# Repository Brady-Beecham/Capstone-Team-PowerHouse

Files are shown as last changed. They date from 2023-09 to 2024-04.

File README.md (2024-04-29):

# Parking Lot Monitoring System: Ground-Based Solution

## Executive Summary

This project is a continuation project from the 2022-23 academic year at Tennessee Technological University to monitor parking lots in a manner that allows students, faculty, staff, and campus visitors to find parking lots with availability in a timely manner. The previous team used cameras to monitor incoming and outgoing traffic in parking lots.  This solution will not work for many of the parking lots that do not have the infrastructure nearby to support cameras.  By using inductive loops to monitor designated entrances/exits of parking lots, more parking lots across campus can be monitored and students, faculty, etc. can find parking availability without having to search an entire parking lot in hopes of finding an open parking spot.

## Capabilities

Though this project is a continuation project, it deviates away from using cameras and instead uses a ground-based solution. 

The project is capable of...

1. Detecting vehicles entering/exiting parking lots that have designated entrances/exits.
2. Detecting vehicles traveling over the loops at 20 miles per hour or less with an accuracy of about 96%.
3. Using LoRaWAN to transmit data from an ESP32 at a designated entrance/exit of a parking lot to the LoRaWAN gateway. The gateway forwards packets to The Things Stack network server. The data is stored in an application on The Things Stack.
4. Utilizing solar power, wall outlet power, and battery power.

## Salient Outcomes

1. This project will continue the work of creating an effective Parking Lot Monitoring System.

   a. As of September 2023, the Parking Lot Monitoring System is in the second year of the overall project.  This team has inherited a previous system that used cameras to complete both static tracking (monitor parked cars) and dynamic tracking (cars entering and exiting lots) to efficiently monitor parking lots.  This method is a very efficient way to monitor parking lots; however, parking lots that are located away from campus buildings or do not have the infrastructure to support camera placement in the lots do not benefit from this method.  By using a ground-based solution to monitor parking lots with designated entrances/exits, more parking lots can be monitored across the campus of Tennessee Tech.

2. This project will implement the use of solar panels to efficiently power the system.

   a. Some parking lots across the campus of Tennessee Tech are not located near campus buildings.  To allow the system to work in these lots, solar panels will be used to power the system at these lots to efficiently monitor these lots so students, faculty, etc. know if there is parking availability at these specific lots.

3. This project will use LoRaWAN to transmit and receive data from the inductive loop sensor.

   a. LoRaWAN has been chosen for its superior range and lower power draw compared to WiFi.

## Project Demonstration & Images

### Project Video
https://www.youtube.com/watch?v=kGD3eaTffT4

### Project Images



*Charge Controller*

Loop Controller

*Loop Controller*



*Power Controller for Solar Power*



*Wall Power Controller*



*ESP32 Microcontroller with RFM95W LoRa Transceiver*



*Raspberry Pi 4-based LoRaWAN Gateway with WM1302 Concentrator*

## About Us

### Team

Abdulrahman Alrudayan is a senior Electrical Engineering major at Tennessee Technological University.  His interests include power systems and digital design.  The main focus for Abdulrahman is designing the main power system that will distribute power to the entire system through the use of buck converters, step-down transformers, etc.

Khalifah Altamimi is a senior Electrical Engineering major at Tennessee Technological University.  His interests include power systems, robotics, and digital design.  The main focus for Khalifah is designing the backup power system that will provide power to allow the system to continue working when a power outage occurs on campus.  When the system is not being used, it will be charging and stay charged until backup power is needed for the system.

Brady Beecham is a senior Computer Engineering major with a minor in Mathematics at Tennessee Technological University.  His interests include embedded system firmware and design. He spent 7 months as an embedded systems software engineering intern at The Coats Company in Lavergne, TN. The main task Brady has is to power the system using solar power and backup batteries. This is going to be designed as an embedded system that will control the charging and discharging status of the batteries.

Kyle Plant is a senior Computer Engineering major with a minor in Computer Science at Tennessee Technological University.  His interests include programming, FPGA, VLSI, networks, embedded systems, artificial intelligence, automation, and more. He has had three internships during his time as an undergraduate. The first two were at Matheson, a producer of industrial, medical, and specialty gasses as well as gas handling equipment. His first internship at Matheson involved making user-friendly GUI dashboards to display graphs of gas purity or mixture ratio data as well as many other small projects. His second internship at Matheson involved performing general site IT duties as well as a few small projects. His third internship was with QMSI or Quality Manufacturing Systems, Inc. QMSI is an automation and systems integration company that specializes in automated pharmacy systems. At QMSI he worked with AutoCAD to make drawings for the conveyor lines and motor panels. The main focus for Kyle is designing a system to collect data from the loop detector, transmit data to a central computer, and store this data in a database within the central computer. This will involve microcontroller programming, wireless networking, and database management.

Michael Sisk is a senior Electrical Engineering major at Tennessee Technological University.  His interests include power systems, robotics, and automation.  He has spent eight months interning at Jack Daniels Distillery in Lynchburg, TN as an engineering maintenance intern.  He is also currently serving as the Engineering Joint Council (EJC) Representative for the student chapter of the Institute of Electrical and Electronics Engineers (IEEE).  The main focus for Michael Sisk is designing the ground-based sensor, which involves using a series of inductive loops to detect the presence of vehicles and determining whether a vehicle is entering or exiting a parking lot from the information given by the loops.

### Faculty Supervisor

Mr. Jesse Roberts - ECE Department

### Stakeholders

The primary customer for this project is the Naval Surface Warfare Center Dahlgren Division in Dahlgren, VA, which is under the command of the Naval Sea Systems Command (NAVSEA). 

One major stakeholder that will be affected by the project is commuter students.  Commuter students will use this system heavily as they must find parking in a timely manner in specific parking lots in order to be on time for class or extracurricular events on campus.

Another stakeholder that will be affected by the project is campus visitors.  For visitors that have come to Tennessee Tech University numerous times or for first-time visitors, it will be extremely useful in locating parking lots that have availability to allow them more time to complete business they have on campus and not have to spend a significant amount of time finding places to park on campus.

### Recognitions

Since this project is a continuation from the 2022-23 academic year, this team wants to recognize the previous Parking Lot Monitoring System team and their members: Kester Nucum, Aaron Wilhite, Gabriel Laboy, Genevieve Schreiber, and Reggie Garza.  This team consisted of three computer engineering students and two electrical engineering students.  With their knowledge and collaboration with the CSC team, they were successful in creating a server, sign, and cameras to detect and count the number of vehicles in a specified parking lot.  Due to their work, this team of three electrical engineering students and two computer engineering students were able to create a ground-based solution to assist the current camera system in detecting vehicles entering and leaving a parking lot and display an accurate number of available parking spots within a specific parking lot.

Another group to recognize for this project is the NAVSEA representatives from Dahlgren, VA: Robert Sexton and Kristen Voyles.  By having their knowledge and expertise of both electrical/computer engineering and the engineering design process, the team was able to learn how to successfully work together as a team while using the knowledge and skills each team member has obtained over the course of their undergraduate education and apply it to a real-world engineering problem.

For this project, the supervisor, Jesse Roberts, held an important role in this project.  Since this is a continuation project, the team relied heavily on Mr. Roberts' input as to what direction the project needed to go and also know the expected output of the project.  With Mr. Roberts' knowledge, the team was successful in finding faults in the previous team's work and was able to find a solution to aiding the use of cameras across parking lots.

## Repo Organization

For the layout of the team's Github, it includes three main folders: Documentation, Reports, and Software.  The three folders are explained in the following subsections.

### Reports

In the Reports folder, it contains documents such as the Project Proposal, Conceptual Design, Experimentation, Final Report, Lessons Learned, etc.  All documentation that is in the form of a report is located in this folder.  This folder also contains a broad explanation of the project from beginning to end in the numerous documents provided in this folder.

### Documentation

In the Documentation folder, folders such as 3D models, signoffs, team meeting minutes, etc. are found in this folder.  This contains very detailed explanations of the design process for the team.  The folder Meeting Minutes contains weekly updates from the team such as discussions between the team and decisions that the team made at these specific meetings.  The folder Electrical contains schematic drawings that were created and also PCB designs that the team used or considered using for the project.  To summarize, the Documentation folder contains very detailed explanations of the different steps in the design process and also the different discussions and decisions made by the team over the course of the project.

### Software

In the Software folder, an explanation of the different software files, code files, etc. is given.  Each software folder contains an explanation of what the software does, all dependencies of the software, how to install the software, and how to use the software.  For those that want to replicate the exact software used for this project, precise detail is given to ensure that the process of using the software is simple to repeat when recreating this project.

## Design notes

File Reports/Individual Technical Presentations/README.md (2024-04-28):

All individual technical presentations created by the team are located in this folder.

Links to Recordings:
-  Kyle Plant LoRa Presentation: https://youtu.be/SCmgpAWQ79U
-  Khalifah Altamimi Power Controller Presentation: https://www.youtube.com/watch?v=OdKJ08sM1yI

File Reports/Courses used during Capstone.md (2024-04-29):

# Abdulrahman Alrudayan
1. ECE 2010, ECE 2020, ECE3300 Circuit I & Circuit II and Electronics I
2. ECE 3610 Intro to Power Systems
3. ECE 3330 Signals and Systems
4. ECE 3210 Control System Analysis

# Khalifah Altamimi
1. ECE 4630 Power Electronics
2. ECE 4610 Power System Analysis
3. ECE 2010, ECE 2020 Circuit I & Circuit II

# Brady Beecham
1.  ECE 4140 Embedded System Design
2.  Circuits I & II, Electronics
3.  CSC 2310 Object Oriented Programming/Design

# Kyle Plant
1.  ECE 4140 Embedded System Design
2.  CSC 4200 Computer Networks
3.  CSC 2500 Unix Lab
4.  CSC 1300, 1310.
5.  Circuits I & II, Electronics

# Michael Sisk
1.	ECE 2050, 3050, 4050: Circuits and Electronics I, II, and III
2.	ECE 3510: Electromagnetic Fields I
3.	ECE 3920: Professional Issues in ECE

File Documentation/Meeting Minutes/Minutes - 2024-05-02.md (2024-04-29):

# Discussions
1. N/A

# Decisions
1. Project is complete and the team station is organized with all equipment used such as batteries, MCUs, PCBs, etc. stored in the boxes on the team station table.
2. All personal equipment such as extension cords, jumper wires, breadboards, etc. is removed from the station and with their original owners.
3. All documentation (schematics, PCB files, images, reports, etc.) is placed in the correct location in the repository folders for the next team to reference and to know where the previous team ended the project.
4. Project was a success and received positive feedback from the department and other organizations such as SGA who want to learn more on how to possibly implement this system across campus after the completion of construction on campus.

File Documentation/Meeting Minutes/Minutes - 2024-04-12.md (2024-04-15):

# Discussions
  - Capstone Poster must be completed by 04/16/2024 at 4:30 pm.  This deadline is non-negotiable as it is the last week it can be printed before the Senior Design Expo.

# Decisions
  - Complete Poster by the end of 04/15/2024 so everyone can review and finalize any changes before submission.
  - Finalize Experimentation and turn Experimentation in.

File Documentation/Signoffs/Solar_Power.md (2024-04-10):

# Solar Power Subsystem
The purpose of the solar power subsystem is to generate energy using solar panels and be able to store energy in the battery. The solar panels utilize a Photovoltaic system to generate the required energy to meet the load's needs. The battery is used to store energy for later consumption when there is no sunlight, making it available for use at night or whenever the solar panel does not deliver the needed voltage and current. The subsystem will supply the necessary rated energy to the other subsystems. By using a charge controller connected to both the solar panels and the backup battery, the charge controller will then transmit the energy to the power controller.

# Constraints
| No. | Constraints | Origin | 
| --- | --- | --- |
| 1.  | The solar panel and the backup battery shall be connected to the charge controller.| System Requirements |
| 2.  | The solar panel should be installed at the right direction and angle that can capture the maximum amount of sunlight. | System Requirements |
| 3.  | The charge controller shall maximize the output power from the solar panel. | System Requirements |
| 4.  | The backup battery shall have enough capacity to prevent the charge controller from discharging more than 50%.| System Requirements |
| 5.  | The backup battery shall either be in the charging or discharging phase, and it cannot be in both simultaneously. | System Requirements |
| 6.  | The  Solar panel and the backup battery wiring shall have a kill switch to disconnect from the charge controller. | System Requirements |

Table 1. Constraints and origins of the constraints.

1. The solar panel and the backup battery will be connected to a charge controller to manage the solar panel output power. Also, it controls the battery charging and discharging phases.     
2. The direction of the solar panels depends on various aspects, as the sunlight differs based on the geographical location. For the case of installing solar panels in North America, the optimal direction is oriented toward facing the south [ 1 ]. Also, the positioning angle of the solar panels plays an essential role in having maximum sunlight. Moreover, it is crucial to place solar panels where they receive direct sunlight, free of obstructions such as trees, buildings, or fences.
3. The charge controller will be responsible for maximizing the output power of the solar panels. The output power of the solar panel can vary throughout the day. Therefore, the charge controller must step up or down the solar panels' output to supply the needed voltages and currents by the loads, including the charging of the backup battery.  
4. The backup battery must have enough capacity to be at most 50% of its capacity while discharging throughout the day of autonomy. The backup battery will have three days of autonomy, which is considered the worst-case.      
5. The backup battery can only perform one procedure at a time. Doing both simultaneously will impact the process of the charging and discharging phase. The charging phase can only occur if it is not discharging simultaneously. On the other hand, The discharging phase can only happen if the battery is not charging simultaneously.
6. A physical kill switch is added to the subsystem for manual control. The kill switch can be used in cases where maintenance is required or to stop either the solar panel or the battery from generating power.

| No. | Subsystem | Voltage | Current |
| --- | --- | --- | --- |
| a.  | Sensor | 9 V | 0.05 A |
| b.  | Data interpretation, Transmission, and Storage | 5.5 V | 0.25 A |
| c.  | Charge Controller | 5.5 V | 0.25 A |

Table 2.  Parameters for the voltages and currents for the subsystems.

# Buildable schematic



*Figure 1. Solar Power Block Diagram*



*Figure 2. Panel Dimensions*    

                                                                                                                                    

 *Figure 3. Single Battery Dimensions*

# Analysis

## Solar Panel
1. The monocrystalline solar panels will be implemented in this subsystem. The common choices when selecting solar panels are between monocrystalline and polycrystalline. The monocrystalline has better efficiency with about 3 % performance ratio [ 2 ]. In this subsystem, the load and the backup battery will require a single solar panel with ratings of 25 W and 12 V. These selections are based on hand calculations by using CEDengineering.com documents that can be found in the course document of “ Design and Sizing of Solar Photovoltaic Systems” course [ 3 ].

Use Table 2 to get the voltage and current required by the three subsystems.
```math
{\rm Power}_{Consumtion} =\ 9\ V\times\ 0.05\ A+\ 5.5\ V\times\ 0.25\ A+\ 5.5\ V\times\ 0.25\ A
```

```math
{\rm Power}_{Consumtion}\ =\ 3.2\ W
```

```math
{\rm Energy}_{Daily}=\ {\rm Power}_{Consumtion}\ \times\ 24\ Hours
```

```math
{\rm Energy}_{Daily}=\ 3.2\ \times\ 24\ Hours
```
```math
{\rm Energy}_{Daily}=\ \ 76.8\ Wh
```

1. W_PV: peak wattage of the array (W_p)
2. E: daily energy requirement (Wh)
3. PSH: average daily number of Peak Sun Hours in the design month for the inclination (hours)

```math

W_{PV}=\ \ \frac{{\rm Energy}_{Daily}}{PSH\ \times\ (\ 0.65\ )}
```

```math
W_{PV}=\ \ \frac{76.8\ Wh}{4.4\ \times\ (\ 0.65\ )}\ =\ 26.85\ W_p
```

2. PV sizing:
The solar panel sizing can be determined by doing steps of calculation. The solar panel for a stand-alone system should be designed to cover the average daily load during the critical design month[3]. The solar panel is sized to satisfy the average daily load requirements for the month or season of the year with a lower ratio of daily insolation to the daily load[ 3 ]. Therefore, according to the Weather Atlas website, the month with the least sunshine average is February, with about 4.4 hours of sunshine [ 4 ]. Using module power output and daily insolation (in peak sun hours), the energy (watt-hours or amp-hours) delivered by a photovoltaic module for an average day can be determined [ 3 ]. Then, knowing the load requirements and the output of a single module, the solar panel can be sized [ 3 ].

```math
Required\ array\ output\ per\ day\left(Wh\right)=\frac{{\rm Energy}_{Daily}}{0.85}\ ;\ \ SLD\ Battery\  Efficiency\ = 0.85
```
```math
    
```
```math
Required\ array\ output\ per\ day\left(Wh\right) =\frac{76.8}{0.85} =\ 90.35\ Wh
```
```math
    
```
```math
Energy\ output\ per\ module\ per\ day\left(Wh\right) = W_{PV}\times4.4 =\ 110Wh\ ;\ \ W_{PV}=25Wh\ \, sunshine\ in\ Feb=4.4
```
The selected array output per Day is W_PV = 30Wh

```math
Energy\ output\ per\ module\ per\ day\left(Wh\right) = 30Wh\times4.4 =\ 132Wh\ ;\ \ W_{PV}=30Wh\ \ and\ the\ sunshine\ in\ Feb=4.4
```

```math
Module\ energy\ output\ at\ operating\ temperature\ (Wh) = 0.8\ \times\ 132\  =\ 105.6Wh  \ ;\ \ rating\ factor\ for\ critical\ applications =\ 0.8
```

```math
 Number\ of\ modules\ required\ to\ meet\ energy\ requirements\ =\ \ \frac{Required\ array\ output\ per\ day}{Module\ energy\ output\ at\ operating\ temperature}
```

```math
 Number\ of\ modules\ required\ to\ meet\ energy\ requirements\ =\ \frac{90.35\ Wh}{105.6\ Wh} =\ 0.86 \approx 1\ module
```

Based on the hand calculations, this subsystem will require one solar module for a rated power of 30 W to satisfy the system requirement.

## Battery

The battery type is Sealed Lead Acid AGM. The sealed lead acid has a depth of discharge of 50%, and the battery's efficiency is 85 %. The two batteries will be connected in parallel to increase the global capacity of the battery, which is rated by amps per hour. Connected batteries are going to charge and discharge through the charge controller. The temperature factor is 1.19.
 
The batteries will be located outdoors; therefore, the discharge capacity according to the temperature should be considered. The discharge capacity for the battery being outdoors for 20 hours at a temperature of -15 C will reduce the battery capacity to 65%.

| No. | Subsystem | Voltage | Current | Rated Wattage[W]| Hours per day used [ h ] | Energy Consumption [ Wh ] |
| --- | --- | --- | ----- | --- | --- | --- |
| a. | Sensor | 9 V | 0.05 A | 9 * 0.05 = 0.45W | 24h | 10.8Wh |
| b. | Data interpretation, Transmission, and Storage | 5.5 V | 0.25A | 5.5 * 0.25 = 1.375W | 24h | 33Wh | 
| c. | Charge Controller | 5.5 V | 0.25 A | 5.5 * 0.25 = 1.375W | 24h | 33Wh |
| | | | | Total Rated Wattage = 3.2W | | Energy Consumption=76.8Wh |

```math
Total\ amp-hour\ demand\ per\ day = \frac{Total\ energy\ demand\ per\ day }{ Battery\ Voltage }
```

```math
Total\ amp-hour\ demand\ per\ day = \frac{76.8Wh }{ 12V }
```

```math
Total\ amp-hour\ demand\ per\ day = {6.4 Ah} 
```
The days of storage are desired to be 3 days ( Autonomy ). Also, the allowable depth of discharge limit is 0.8.
Using the given values, we will be able to calculate the required battery capacity ( Ah)
```math
Required\ battery\ capacity (Ah)  = \frac{ amp -  hour\ demand\ per\ day \ \times\ Days\ of\ Autonomy } { Depth\ of\   discharge }
```

```math
Required \ battery \ capacity \ (Ah)  = \frac{ 6.4Ah \ \times\  3\ days } { 0.8 }
```
```math
Required \ battery \ capacity \ (Ah) = {24 Ah} 
```

For a battery capacity of 24 Ah, increasing the battery capacity is considered a good practice when choosing battery capacity for a solar power system. Also, considering the depth of discharge and other loss power factors, the desired battery capacity will be 40 Ah, which means we will need two batteries with 12 V and 20 Ah in parallel. Since connecting a battery in parallel will increase the battery capacity, the battery capacity will increase to 40 Ah, and the battery voltage will remain the same at 12 V.

## Connection Between Solar Power Subsystem and Charge Controller Subsystem

### Solar Panel to Charge Controller

The solar power subsystem is connected to the charge Controller to maximize the output power from the solar panel during the sunlight hours. The solar panel output is connected to the charge controller through a wire that outputs 30 watts at optimal conditions. As the charge controller subsystem is delivering 12 V for the battery and the power controller, that means it could have up to 2.5 A using P = V * I to charge the battery and feed the power controller with the needed current. Therefore, the charge controller subsystem is going to maximize whatever wattage is being delivered from the solar panel and ensure it will satisfy the required voltage and current from both the battery and the power controller. 

To be able to deliver the needed voltage and current, the charge controller uses an MPPC method that includes a current sensor, Arduino Nano, Pulse Width Modulation, and Output Circuit. The advantage of using MPPC is that if the solar panel does not satisfy the needed voltage. The MPPC will increase the voltage to 12 V using a Buck-Boost IC. However, using just the Buck-Boost IC will not be enough since it needs to control different outputs that are connected to the charge controller. Therefore, the charge controller will use a certain logic through a pulse width modulation to optimize the output of the solar panel and then charge or discharge the battery and deliver the needed voltage and current to the power controller subsystem.



Figure 4: Connection between the solar panel and the charge controller that includes the MPPC, current sensor, pulse width modulation, and battery charge and discharge switching logic



*Figure 5: LTC4020 Schematic that has a range of input voltages from 4.5 V to 55 V and handles the different charging modes for sealed lead acid batteries.

For more details, refer to the charge controller subsystem[ https://github.com/Brady-Beecham/Capstone-Team-PowerHouse/blob/main/Documentation/Signoffs/Charge_Controller.md ]

# BOM
| Part | Part Number | Quantity | Price Per Unit | Total Price |
| --- | --- | --- | --- | --- |
| Solar Panel | AM-L02P25-1 | 1 | $35.99 |  $44.79 |
| Seal Lead Acid | ML12-12F2 | 2 | $27.99 | $55.98 |
| Total | ----- | ----- | ----- | $91.97 

Solar Panel: https://www.amazon.com/Newpowa-High-Efficiency-Monocrystalline-Designed-Battery/dp/B00W81BZTO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

Seal lead acid Battery: https://www.amazon.com/ML12-12-Battery-Terminal-Mighty-Product/dp/B00K53FG5Q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

# References
1. “Best direction for solar panels:,” Maximize Efficiency: Best Direction for Solar Panels”, https://www.sunrun.com/knowledge-center/best-direction-for-solar-panels (accessed Oct. 31, 2023).
2. H. Fitria, ”The effect of monocrystalline and polycrystalline material structure on Solar Cell Performance”,https://www.researchgate.net/publication/347745141_The_effect_of_monocrystalline_and_polycrystalline_material_structure_on_solar_cell_performance (accessed Nov. 1, 2023).
3. “Design and sizing of solar photovoltaic systems,” www.cedengineering.com, https://www.cedengineering.com/courses/design-and-sizing-of-solar-photovoltaic-systems (accessed Nov. 1, 2023).
4. Weather Atlas, “Yearly & Monthly Weather - Cookeville, TN,” Weather Atlas, https://www.weather-atlas.com/en/tennessee-usa/cookeville-climate (accessed Nov. 2, 2023).

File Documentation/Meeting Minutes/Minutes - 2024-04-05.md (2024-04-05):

# DISCUSSIONS
## Team Meeting
### 1) Brady Beecham - Charge Controller Subsystem and Solar Power Subsystem
a) Restart testing on battery charging PCB
### 2) Abdulrahman Alrudayan - Main Power Subsystem
a) Work on Github for Lessons Learned and updating Github, Capstone Poster, and Capstone Final Presentation
### 3) Khalifah Altamimi - Power Controller Subsystem
a) Work on Github for Lessons Learned and updating Github, Capstone Poster, and Capstone Final
Presentation
### 4) Kyle Plant - Data Interpretation/Transmission Subsystem
a) Connect ESP32 to function generator to test the frequency

b) P-Count Driver is out of date and will migrate to the new P-Count Driver.
### 5) Michael Sisk - Loop Controller Subsystem
a) Work on Github for Lessons Learned and updating Github, Capstone Poster, and Capstone Final Presentation
## NAVSEA Meeting
### 1) Capstone Poster/Final Presentation
a) Use more pictures over words

b) Smaller subsystems make brief due to Loop Controller and Data Subsystems having information

c) With subsystems that do not work, treat the presentation as a "if the team had another semester of work, how would we resolve the issues faced?" type of situation.
# DECISIONS
1) Experimentation must be complete by 04/07/24.
2) Two weekly meetings for the final weeks to complete both poster and presentation.

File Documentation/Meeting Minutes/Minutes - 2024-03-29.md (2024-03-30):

# DISCUSSIONS
## Team Meeting
### 1) Brady Beecham - Charge Controller Subsystem and Solar Power Subsystem
a) Due to the lack of time, automatic charging of
the batteries will not happen. This will require the
batteries to be manually charged. Will be capable
of swapping from Solar to Batteries though.

b) Work with Conrad on the subsystem to complete
as much as possible.

c) Talk with Roberts and alert him of the issues and
what can be traded off due to this issue.
### 2) Abdulrahman Alrudayan - Main Power Subsystem

a) Experimentation/Testing of subsystem
### 3) Khalifah Altamimi - Power Controller Subsystem

a) Experimentation/Testing of subsystem
### 4) Kyle Plant - Data Interpretation/Transmission Subsystem
a) Finalize all details and test the entire system for
experimentation on 03/27/2024
### 5) Michael Sisk - Loop Controller Subsystem
a) Finalize details for Experimentation for the Github.
## NAVSEA Meeting
1) N/A as meeting did not happen this week.
# DECISIONS
1) Review Measures of Success for the Experimentation phase and if each measure of success is met or not and explain the logic behind it.
2) Complete Experimentation phase and move into finalizing the Parking Lot Monitoring System and prepare the project to be moved to the next team in the Fall 2024 semester while also preparing for the Spring 2024 Senior Design Expo.

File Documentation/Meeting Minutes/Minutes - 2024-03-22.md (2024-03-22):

# DISCUSSIONS
## Team Meeting
### 1) Brady Beecham - Charge Controller Subsystem and Solar Power Subsystem
a) Continue work on Charge Controller PCBs fabrication
### 2) Abdulrahman Alrudayan - Main Power Subsystem
a) Prepare experiments for the Main Power Experimentation
### 3) Khalifah Altamimi - Power Controller Subsystem
a) Prepare experiments for the Solar Power Experimentation
### 4) Kyle Plant - Data Interpretation/Transmission Subsystem
a) Test the Data Subsystem and verify the subsystem works accordingly. If not, resolve issues before Experimentation phase.
### 5) Michael Sisk - Loop Controller Subsystem
a) Help other teammates out where help is needed to continue progress on the project.
## NAVSEA Meeting
### 1) Brady Beecham - Charge Controller Subsystem and Solar Power Subsystem
a) Issues with MPPC PCB that is taking longer than expected to troubleshoot

b) Plan is to bypass MPPC

c) Battery Charger PCB is complete and is going through testing currently.

d) Developing a solution to test subsystem
### 2) Abdulrahman Alrudayan - Main Power Subsystem
a) Subsystem is working correctly and waiting for experimentation
### 3) Khalifah Altamimi - Power Controller Subsystem
a) Subsystem is working correctly and waiting for experimentation
### 4) Kyle Plant - Data Interpretation/Transmission Subsystem
a) LoRaWAN up and running

b) Pulse counter still experiencing issues due to timing and needing another library to monitor microseconds instead of milliseconds
### 5) Michael Sisk - Loop Controller Subsystem
a) Subsystem is working correctly and waiting for experimentation
### 6) Experimentation Phase
a) Have requirements and map out incremental evidence that will prove it works properly

b) Check each piece and do unit testing and build upon each unit, from beginning to end

c) Unit experimentation will work best as we can start and then build off good results

d) Power first, Loop Controller second, Data System third
# DECISIONS
1) Experimentation will happen on 03/24/2024 at 1 pm to
test current subsystems: Wall Power, Solar Power with
Batteries, Loop Controller, and Data System. Charge
Controller will not be available for experimentation yet
as it has experienced issues that is moving completion
time to a later date.

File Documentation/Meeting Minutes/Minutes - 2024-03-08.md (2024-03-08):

# DISCUSSIONS
## Team Meeting
### 1) Brady Beecham - Charge Controller Subsystem and Solar Power Subsystem
#### a) Focus is on fabrication, Main PCB for Monday, Battery Charger PCB for Tuesday and any code
#### b) Plan to have everything complete Thursday
### 2) Abdulrahman Alrudayan - Main Power Subsystem
#### a) Finish fabrication and start testing of subsystem individually for desired values
### 3) Khalifah Altamimi - Power Controller Subsystem
#### a) Plan is to connect Solar Power to Charge Controller with Brady and verifying subsystem works
#### b) Submit Minimum Prototype for Solar Power and Power Controller
### 4) Kyle Plant - Data Interpretation/Transmission Subsystem
#### a) Get LoRaWAN to work on ESP32 (establish connections)
#### b) Resolve corrupt firmware problem
#### c) Update pulse counter in Arduino code for the ESP32
### 5) Michael Sisk - Loop Controller Subsystem
#### a) Help other teammates out where help is needed to continue progress on the project.
## NAVSEA Meeting
### 1) Brady Beecham - Charge Controller Subsystem and Solar Power Subsystem
#### a) Not available but update for the subsystems was given by Michael Sisk
### 2) Abdulrahman Alrudayan - Main Power Subsystem
#### a) Update of subsystems including issues faced and how issues were resolved
#### b) Issue right now is current testing
### 3) Khalifah Altamimi - Power Controller Subsystem
#### a) Update of subsystems including issues faced and how issues were resolved
#### b) Issue right now is current testing
### 4) Kyle Plant - Data Interpretation/Transmission Subsystem
#### a) Update of the progress of the Data Subsystem
### 5) Michael Sisk - Loop Controller Subsystem
#### a) Update of the progress of the Loop Controller and Inductive Loops
# DECISIONS
1) Experimentation of the project will not start until all
subsystems have passed unit tests and work accordingly.
This is necessary as the subsystems do not need to be
connected to each other until everything works properly
to avoid causing unintended damage to other subsystem
components.

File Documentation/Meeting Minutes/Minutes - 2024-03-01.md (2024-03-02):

# DISCUSSIONS
## Team Meeting
### 1) Brady Beecham - Charge Controller Subsystem and Solar Power Subsystem
  #### a) Assist Khalifah with testing of subsystem
  #### b) Help Kyle with coding for Data Subsystem
  #### c) Complete SMD soldering for one component on the Loop Controller
  #### d) Assist others in fabrication of other PCB fabrication
### 2) Abdulrahman Alrudayan - Main Power Subsystem
  #### a) Help others with PCB fabrication until parts arrive.
### 3) Khalifah Altamimi - Power Controller Subsystem
  #### a) Change resistors out for voltage change
  #### b) Help with soldering other PCB boards
### 4) Kyle Plant - Data Interpretation/Transmission Subsystem
  #### a) ESP32 LoRaWAN communication needs to be established
  #### b) Review code of Charge Controller for Brady
  #### c) Write the code for the communication of ESP32
  #### d) Establish Github documentation for code in the event that something happens
### 5) Michael Sisk - Loop Controller Subsystem
  #### a) Start assembly of Loop Controller once everything has arrived
## NAVSEA Meeting
  1) N/A as team does not meet with NAVSEA this week
# DECISIONS
  1) Power Controller and Loop Controller are almost complete and fully functional.
  2) Have as many subsystems functional as possible before the deadline on 03/05/24.

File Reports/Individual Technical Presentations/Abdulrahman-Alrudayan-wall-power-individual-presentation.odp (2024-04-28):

## Wall power

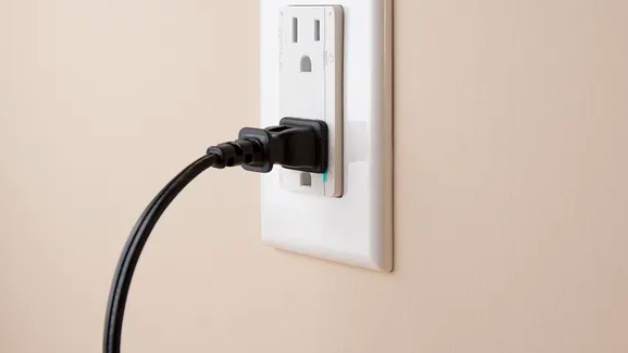
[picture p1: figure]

By Abdulrahman Alrudayan

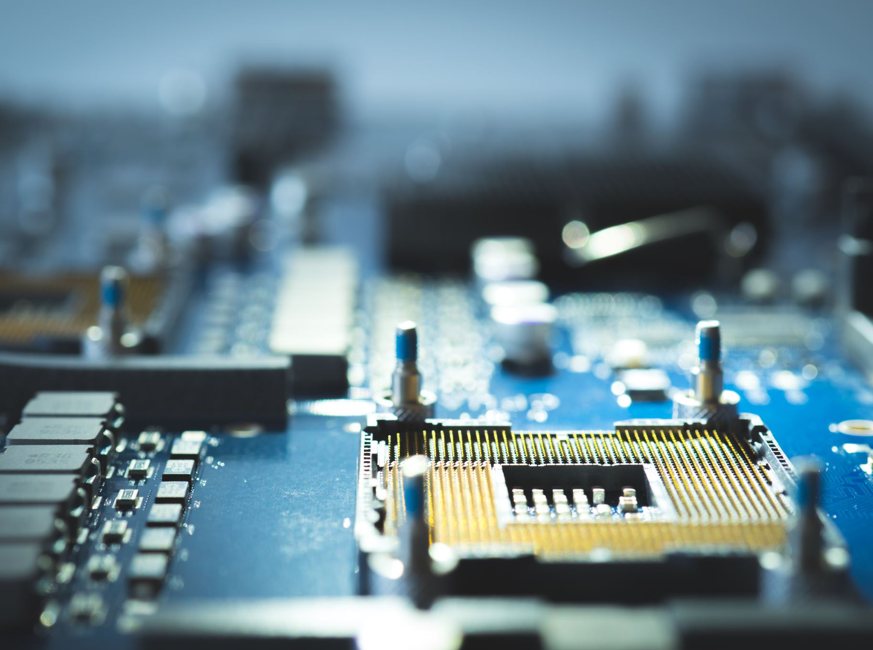
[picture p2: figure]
Electronic circuit board

- What the process?
- Adapter Power Supply AC to DC Plug
- Converters Buck
- Backup Battery 12v
- Relay switch
- Kill switch

## Main Wall Power Subsystem

- Adapter Power Supply:
- Converts AC to 12V DC

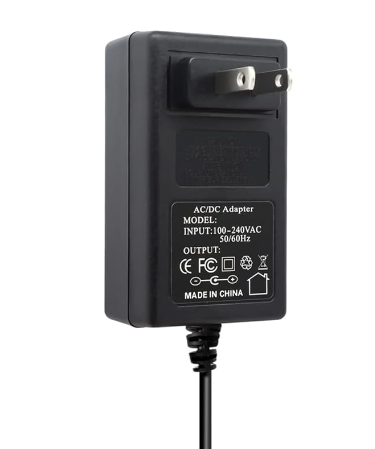
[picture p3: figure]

## Buck Converters:

- Step down the voltage
- First subsystem “Data interpretation and Storage” : To +5.5V DC, 0.25A
- Second subsystem “Sensor” : To +9V DC, 0.05A

## Selecting and size First subsystem

- Buck Converter : LTC3621
- First subsystem “Data interpretation and Storage” : To +5.5V DC, 0.25A

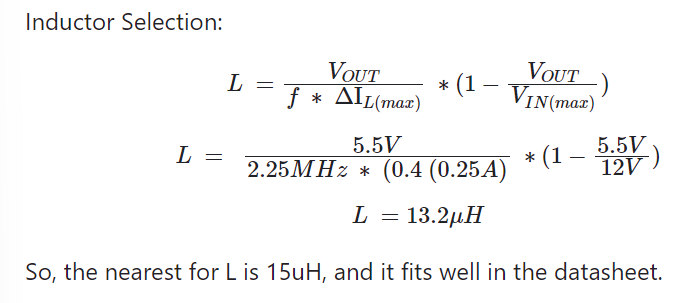
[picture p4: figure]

## Feedback resistors Selection and Input Capacitor :

- Output Capacitor: As given in the Datasheet, the Input Capacitor is 22uF.

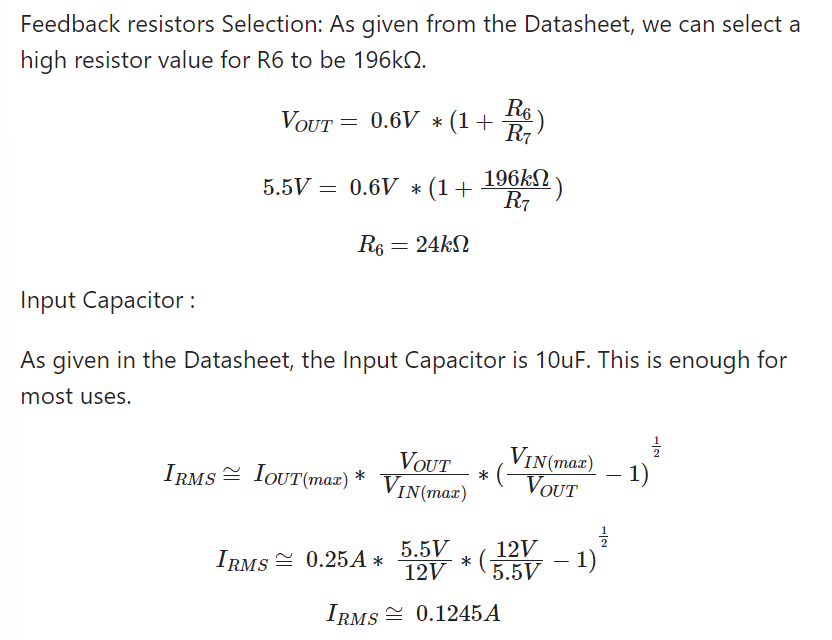
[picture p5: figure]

## Selecting and size Second subsystem : Sensor

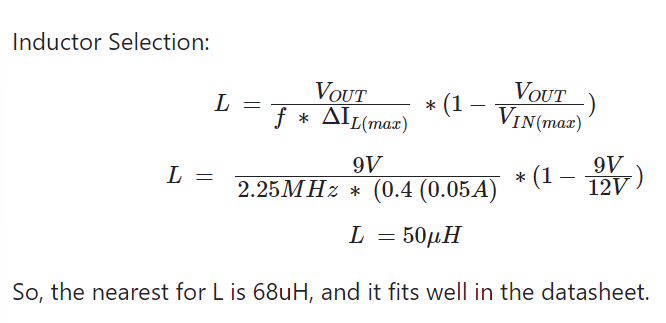
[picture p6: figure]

## Feedback resistors Selection and Input Capacitor :

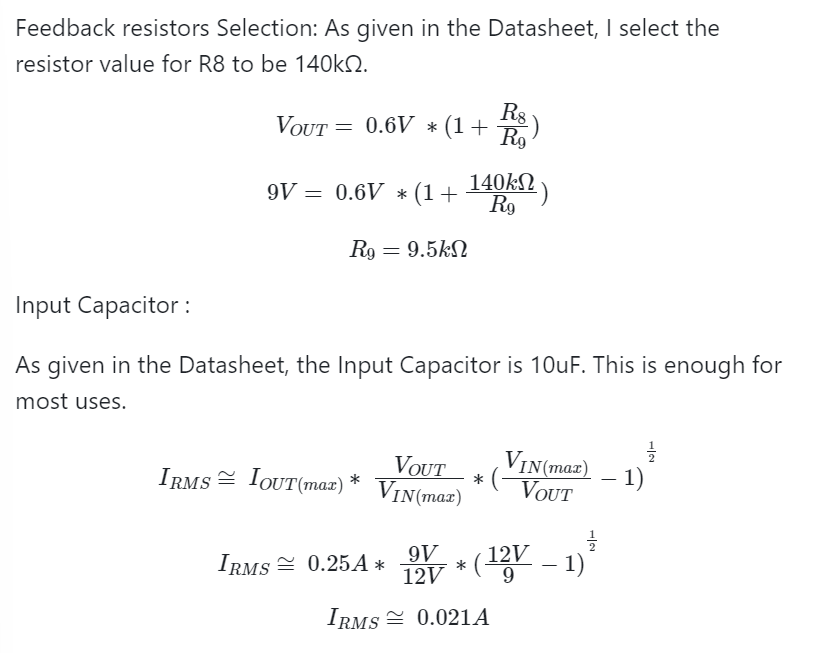
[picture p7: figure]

- Output Capacitor:
- As given in the Datasheet,
- the Input Capacitor is 22uF.
- This is best for use.

## LTspice

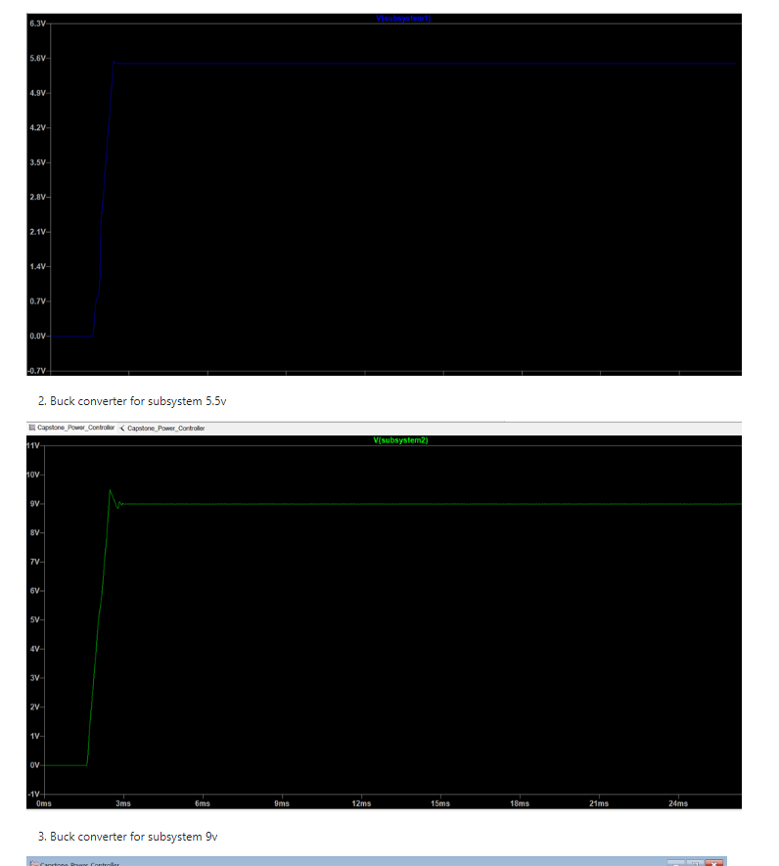
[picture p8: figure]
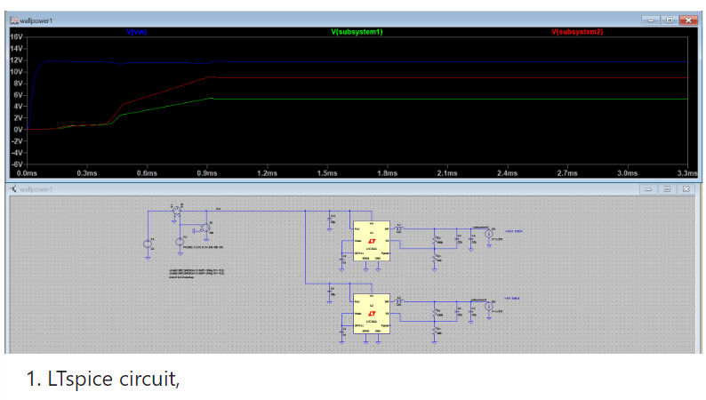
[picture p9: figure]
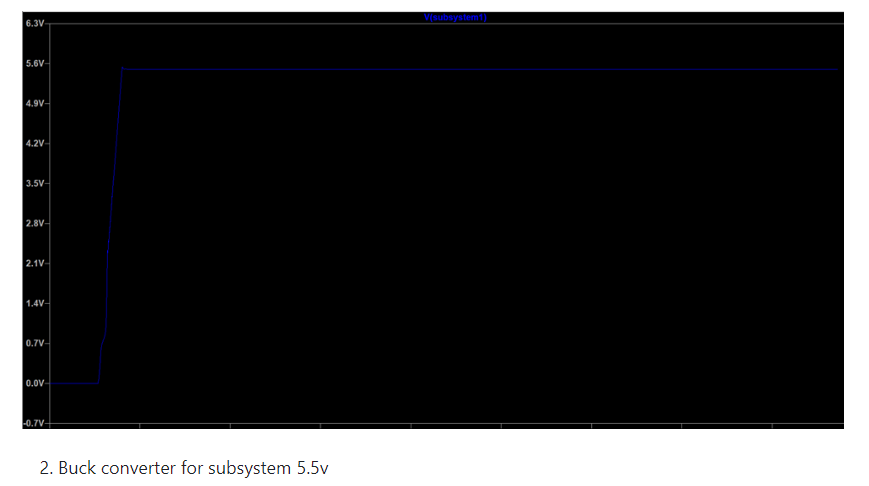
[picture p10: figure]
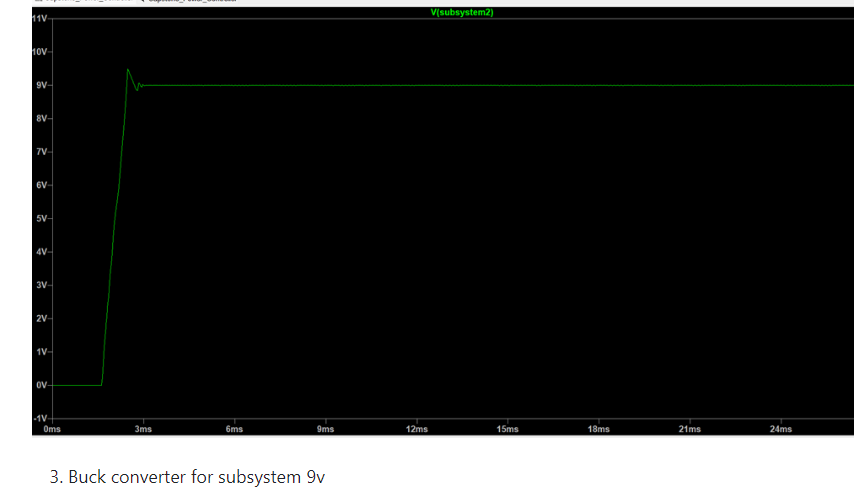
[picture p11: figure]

## Controller:

- Manage power flow between main wall power and backup power
- Used relay to switch between power
- Kill switch for safety

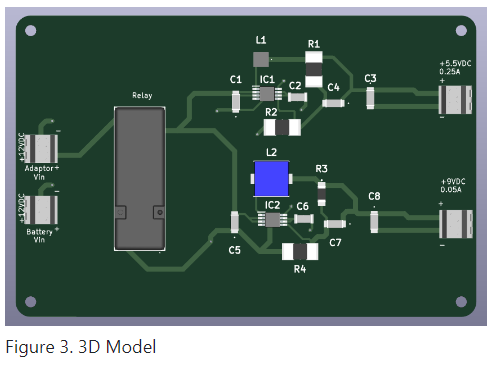
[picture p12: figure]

- Thank you !

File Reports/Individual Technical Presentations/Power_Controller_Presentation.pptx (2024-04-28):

## Power Controller

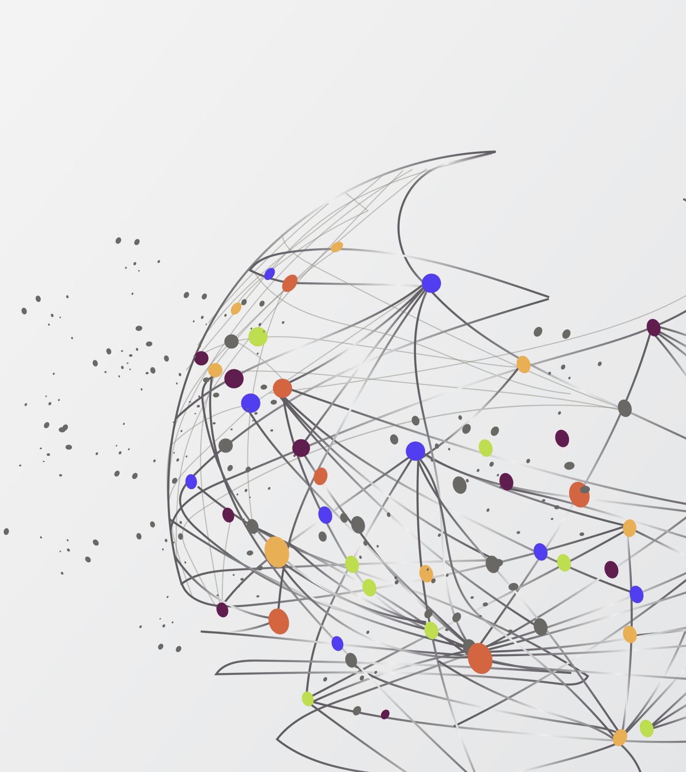
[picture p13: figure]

## Voltage Regulators

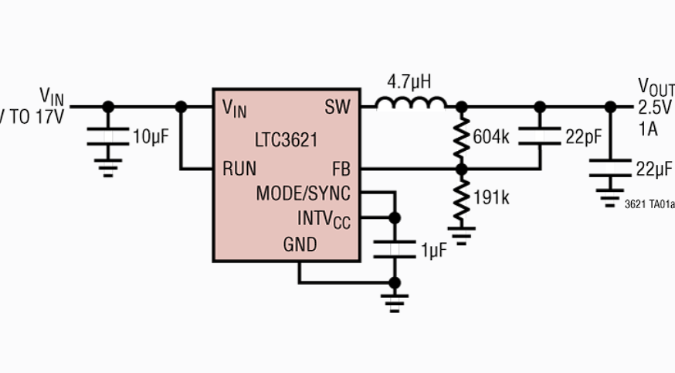
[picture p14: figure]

- Buck-Boost Converter
- Buck Converter
- Boost Converter

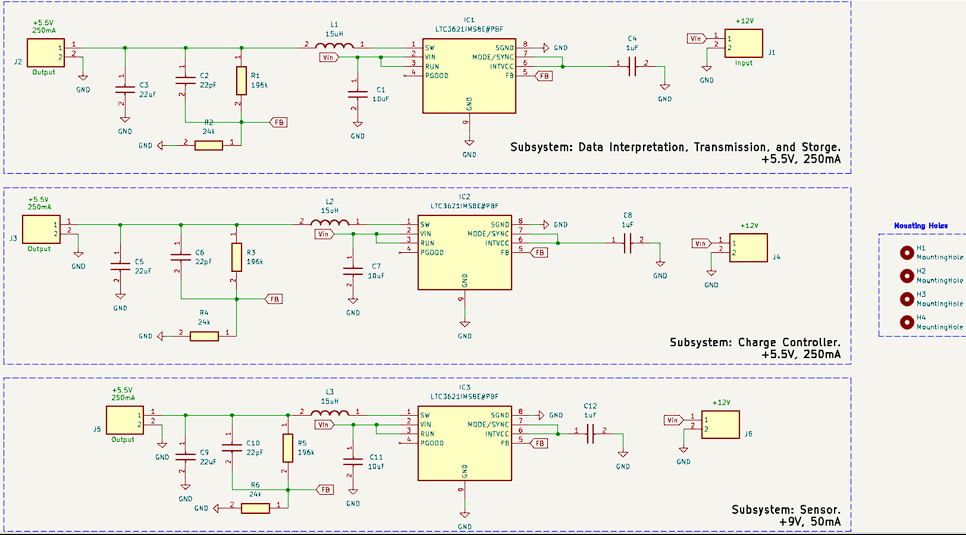
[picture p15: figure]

## Buck Converter

- LTC3621 17V, 1A Synchronous Step-Down Regulator with 3.5μA Quiescent Current
- Wide VIN Range: 2.7V to 17V
- Wide VOUT Range: 0.6V to VIN
- 95% Max Efficiency
- Constant Frequency (1MHz/2.25MHz)

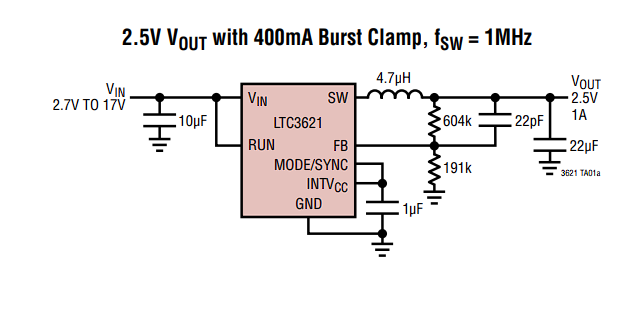
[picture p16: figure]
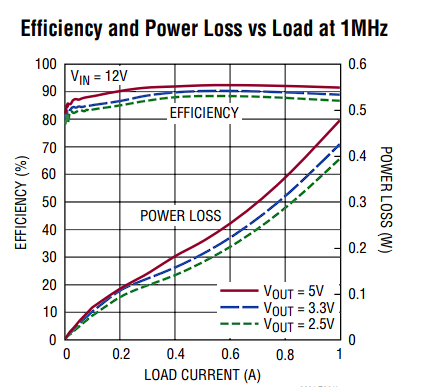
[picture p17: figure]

## Sizing and selecting for Buck Converter

No. | Subsystem | Voltage | Current
a | Data interpretation, Transmission, and Storage | 5.5 V | 250 mA
b | Charge Controller | 5.5 V | 250 mA
c | Loop Controller | 9 V | 50 mA

## Sizing and selecting for Buck Converter

No. | Subsystem | Voltage | Current
a | Data interpretation, Transmission, and Storage | 5.5 V | 250 mA
b | Charge Controller | 5.5 V | 250 mA

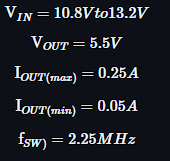
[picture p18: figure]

Inductor Selection: For starting point is to choose the ripple current to be %40 of I_out(max). To ensure that the ripple current does not exceed the specified maximum.
Given this, a 14.26µH, we can pick the inductor as 15µH, which would suffice

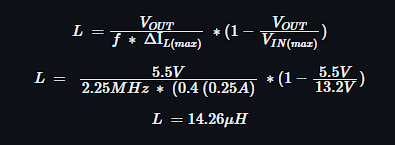
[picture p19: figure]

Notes: Inductor Selection: For starting point is to choose the ripple current to be %40 of I_out(max). To ensure that the ripple current does not exceed the specified maximum.

## Sizing and selecting for Buck Converter

- Ripple Current Selection

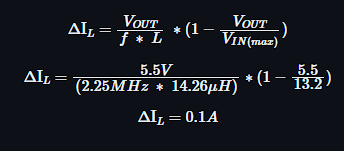
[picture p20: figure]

- Feedback resistors Selection:

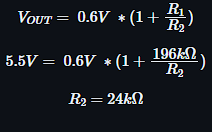
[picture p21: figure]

## Sizing and selecting for Buck Converter

- Input Capacitor Selection = 10µF ceramic capacitor
- I_(RMS) Value

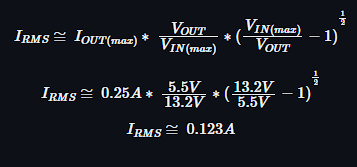
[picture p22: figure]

- Output Capacitor Selection:
a 22µF ceramic capacitor is selected

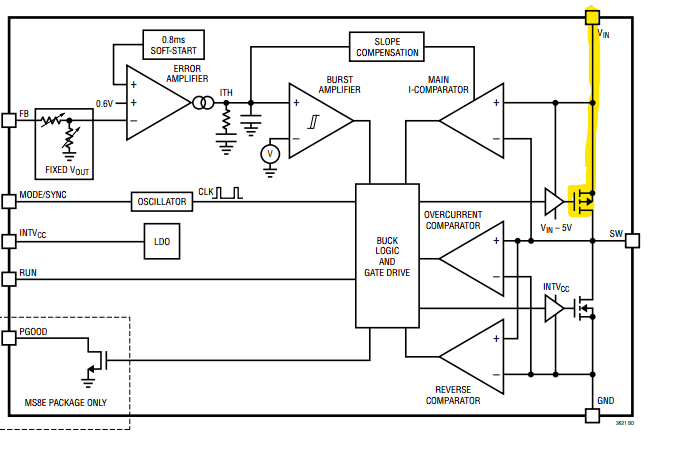
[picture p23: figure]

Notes: The input capacitance, CIN, is needed to filter the square wave current at the drain of the top power MOSFET. To prevent large voltage transients from occurring, a low Equivalente Series Resistance ESR input capacitor sized for the maximum RMS current should be used. The maximum RMS current is given by

## Sizing and selecting for Buck Converter

No. | Subsystem | Voltage | Current
c | Loop Controller | 9 V | 50 mA

Inductor Selection: For starting point is to choose the ripple current to be %40 of I_out(max). To ensure that the ripple current does not exceed the specified maximum.
Given this, a 63,63µH, we can pick the inductor as 68µH, which would suffice

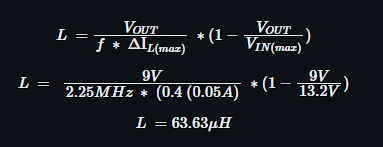
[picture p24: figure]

## Sizing and selecting for Buck Converter

- Ripple Current Selection


- Feedback resistors Selection:


## Sizing and selecting for Buck Converter

- Input Capacitor Selection = 10µF ceramic capacitor
- I_(RMS) Value


- Output Capacitor Selection:
a 22µF ceramic capacitor is selected

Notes: The input capacitance, CIN, is needed to filter the square wave current at the drain of the top power MOSFET. To prevent large voltage transients from occurring, a low Equivalente Series Resistance ESR input capacitor sized for the maximum RMS current should be used. The maximum RMS current is given by

## LTSpice Simulation


## Kicad

## Experiments Result

No. | Subsystem | Expected Voltage | Actual Voltage | Expected current | Actual current
a | Data interpretation, Transmission, and Storage | 5.5 V | 5.34 V | 250 mA | 217.26 mA
b | Charge Controller | 5.5 V | 5.31 | 250 mA | 216.42 mA
c | Loop Controller | 9 V | 9.57 V | 50 mA | 54.49 mA

## Reference

1. Ltc3621-3621-2.Pdf - Analog Devices, www.analog.com/media/en/technical-documentation/data-sheets/ltc3621-3621-2.pdf. Accessed 23 Mar. 2024.
2. Ti, www.ti.com/lit/an/slva301/slva301.pdf?ts=1694361856373. Accessed 23 Mar. 2024.

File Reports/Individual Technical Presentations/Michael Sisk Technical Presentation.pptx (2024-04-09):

## Loop Controllers for Vehicle Detection

By: Michael Sisk

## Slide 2


## Examples of Loop Controllers


## Loop Controller

- Loop Controller consists of two circuits: Colpitts Oscillator and Sine to Square Wave
- Colpitts Oscillator
  - Consists of a capacitive voltage divider and an inductor (inductive loop) that generates a stable frequency


## Loop Controller cont.


## Loop Controller Frequency

- The math
- Set values: L = 100 µH, C1 = 220 nF, C2 = 100 nF
- f0 = 60 kHz

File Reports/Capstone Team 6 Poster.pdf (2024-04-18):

## Abdulrahman Alrudayan Khalifah Altamimi Brady Beecham Kyle Plant Michael Sisk

# Parking Lot Monitoring System -

# Ground Based Approach

# Overview


The goal of the project is to develop an inductive loop-based system to determine the number of available parking spaces in a parking lot. The project is being designed as a proof-of-concept system that can be scaled up to span the entirety of campus.


Team | Results


# Acknowledgements

Special thanks to Mr. Jesse Roberts and our NAVSEA representatives, Rob Sexton and Kristen Voyles, for their guidance and involvement in this project.

# Design

Left to Right: Abdulrahman, Brady, Khalifah, Kyle, Michael

Figure 2: Project Block Diagram


Figure 5: System Implementation


Figure 1: Project Hardware

Power System Capabilities
Two power systems are available for use:
1. Wall Power system that connects to a wall outlet and a backup battery in the event of power loss.
2. Solar Power system that connects to a solar panel and charge controller with two backup batteries if the sun is not visible.

Ground Based Sensor Capabilities The Loop Controller generates a sinusoidal wave to send through the inductive loops placed in the roadway for vehicle detection. The response from the inductive loops is converted into square waves that are sent to the ESP32 MCU.
Data System Capabilities
The ESP32 detects changes in frequency and determines if a vehicle is entering or exiting a parking lot using its thresholding algorithm. This data is saved locally and transmitted at regular intervals to the LoRaWAN cloud server.

# Future Work

1. Test against numerous vehicle classifications and how the frequency changes with each classification of vehicle.
2. Upgrade LoRaWAN equipment.
3. Improve vehicle detection algorithm.
4. Redesign Charge Controller PCB
5. Integrate LoRaWAN cloud server data with the previous ECE team’s mobile application.

Figure 3: Frequency vs Time (5 mph) Figure 4: Frequency vs Time (15 mph)

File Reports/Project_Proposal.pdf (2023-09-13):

# Project Proposal for Parking Lot Monitoring System

Abdulrahman Alrudayan, Khalifah Altamimi, Brady Beecham, Kyle Plant, Michael Sisk
Electrical and Computer Engineering Tennessee Technological University Cookeville, TN
aaalrudaya42@tntech.edu, kyaltamimi42@tntech.edu, bkbeecham42@tntech.edu, klplant42@tntech.edu, mtsisk42@tntech.edu

Abstract—Commuter students at Tennessee Technological University often face the difficulty of finding available parking in lots during the day. Due to the numerous products on the market being either expensive or not feasible for the campus of Tennessee Technological University, a parking lot monitoring system designed by students from the Electrical and Computer Engineering Department, in collaboration with the Department of Computer Science from Tennessee Technological University, can prove that there is a more cost-effective option that fits the needs of the university and its parking lots. This project along with the collaboration between the two departments will be under the direction of the Naval Sea Systems Command (NAVSEA) in Dahlgren, VA. This project is a continuation project from the 2022-23 academic year

I. INTRODUCTION

In a period of expanding enrollment and the need for convenient parking options, Tennessee Tech University in Cookeville, Tennessee, presents a particular parking dilemma. At this university, students can buy affordable purple parking passes that let them park in distant lots or more expensive red parking passes that allow parking closer to the academic buildings. The appeal of shorter commutes to the center of campus results in a strong demand for red parking passes. With the strong demand and limited supply, students can be hard pressed to find good parking, particularly during peak hours. There are 5,762 total parking places on campus [1], 2,388 are designated as red parking spots and 10,117 students enrolled as of Fall 2023 [2]. The amount of enrolled students is nearly double the amount of total parking places on campus. Students’ preference for parking as close to their academic buildings as possible, which causes congestion in parking lots, only worsens this parking situation. This project’s goal is to create a proof of concept for a system that counts the number of vehicles in a specific parking lot. The system hopes to accomplish this by offering simple access to real-time information about parking spot availability via signage or a mobile application. However, to achieve this goal, the project must abide by several requirements and limitations. These include adhering to regulations like the IEEE 802.11 Wireless Local Area Networks for wireless communication and the National Fire Protection Association (NFPA) 70 and 70E Electrical

Standards and Codes for electrical safety. Additionally, if pneumatic tubes are used for vehicle counting, ISO 4414 compliance is required. The Tennessee Hands-Free Law, which forbids using a mobile device while operating a vehicle, also raises moral questions about the use of mobile applications, necessitating possible safety features or educational projects. With the help of modern technology, this project aims to solve Tennessee Tech University’s critical parking problem while also ensuring the convenience and safety of the student body.

II. IDENTIFIED PROBLEM

A. Background Information
The parking monitoring sensor will be implemented at Tennessee Tech University, located in Cookeville, Tennessee. At this university, commuter students have two options when it comes to parking passes: they can opt for the more affordable purple passes, which grant them access to parking spaces on the outskirts of the campus, or they can choose the more expensive red passes. The red passes, while pricier, provide the advantage of parking closer to the buildings where students attend their classes, reducing the walking distance to just about a 5-minute stroll to reach their classrooms.
However, there is a significant challenge associated with the red passes, which is the high demand for these premium parking spots. This high demand often leads to difficulties in finding available parking spaces, especially during the early morning rush when many students are arriving on campus, causing congestion in the parking areas.
To put this issue into perspective, Tennessee Tech University’s campus has a total of 5,762 parking spots [1], out of which 2,388 are designated as red parking spots. Considering the university’s student population as of Fall 2023, which stood at 10,117 students [2], it becomes evident that the demand for parking spots is considerably high. Additionally, a contributing factor to this parking dilemma is that students generally prefer to secure parking spots as close as possible to the buildings they have classes in, exacerbating the parking congestion.
B. Goal of This Project
The goal of this project is to design a proof of concept for a vehicle counting system that will be able to keep track of the number of vehicles in a given parking lot so that the number of empty parking spaces can be determined. The information of the number of empty parking spaces will be sent where it can be quickly viewed such as a sign or mobile application.
C. Specifications and Constraints
1) Specifications:
- System shall not obstruct any parking spots on campus in a way that would not allow a person to park in a given spot.
- System shall not interfere with parking traffic on campus in a way that would cause traffic to worsen.
- System shall operate during parking enforcement hours of 8am - 4:30pm.
- System shall have outdoor signage to indicate parking availability to people searching for parking on campus.
- System shall show data relevant to parking availability.
- System shall have detailed documentation about the system’s design and operation so future owners of the system can easily make adjustments to and maintain the system.
- System shall have a system of sensors to get count of vehicles present in parking lots.
- System shall have notification posted on mobile application about potential decreased system accuracy during inclement weather.
- System shall have notification posted on mobile application about dangers of driving while using a mobile device as well as its illegality in Tennessee on app startup.
- System shall not permanently store images. System shall not record videos.
- Shall have a ground monitoring system with a system of sensors capable of distinguishing cars from pedestrians and determining whether the car is entering or exiting the lot.
- System shall have a re-calibrate function in the event that sensors are returning inaccurate counts not due to external factors (e.g. weather, physical damage).
- System shall have protection against inclement weather (e.g. rain, snow).
- System shall have a mobile application for people wanting to check information about availability of parking on campus.
- System shall save data related to number of cars in parking lot at given times.
- System shall, at a minimum, perform its intended function in ideal conditions (i.e. clear weather)
- System shall have counts within at least 90% accuracy compared to the true counts.
- System shall have notification posted on mobile application if system is not fully operational due to system malfunctions (e.g. parts of the system are damaged).
2) Standards: The following are potential standards and regulations that continue to provide additional constraints [1]: National Fire Protection Association (NFPA) 70 and 70E Electrical Codes and Standards - This standard is intended to safeguard persons and property from hazards arising from the use of electricity. This standard will be followed to ensure electrical safety of the system and of the working environment as the team is building and testing the system [6][7].
IEEE 802.11 Wireless Local Area Networks- This standard specifies the set of media access control and physical layer protocols for implementing wireless local area network computer communication. This standard will be following when designing any wireless communication between any sensors or servers [8].
ISO 4414 Pneumatic fluid power- This standard specifies general rules and safety requirements for pneumatic power systems and components. These standards should be followed if any pneumatic tubes are to be used to count vehicles [9]. Tennessee Code Annotated 55-8-199 - more commonly known as the Tennessee Hands Free Low, prohibits the act of holding a cellphone or mobile device using any part of one’s body as illegal, in which only hands free devices are to be used while driving a motorized vehicle [10]. Taken into effect in July 2019, this state law raises ethical implications with regards to the possible usage of our mobile application while driving by students, which may cause a need to address some type of safety feature for the project to either educate or protect the user against misuse of the app related to the law.
3) Externalities: During the planning and design phases, it is important to take into account all potential positive and negative externalities that may arise from Tennessee Tech University’s development and implementation of the Parking Lot Monitoring System.
Pedestrian Safety: There is an apparent concern for the safety of pedestrians navigating through the campus parking lots or sidewalks without encountering safety hazards or disruptions caused by the parking monitoring system. Also, the parking monitoring system complies with the accessibility guidance.
Economic Implications: The system could have economic externalities, potentially increasing parking costs for some users, if it implemented dynamic pricing based on demand or charged fees for gold, red, or green parking spaces. Also, This might include having resources to monitor and maintenance team and fix any issues with the system during its operational time which could include systems losing power, damage to the signage, sensor resets, etc.
D. Stakeholders
TODO: maybe add organizations as stakeholder The implementation of a Parking Monitoring Sensor System is going to play a crucial role in our campus community. It will enhance the overall college experience for everyone involved. There will be many users of the parking sensor monitoring system as students, faculty members, and visitors. Nowadays, parking tracking is a mandatory requirement, especially with the rising student population and the sudden constructions within the campus. Using parking sensors has many advantages, especially for car users whether it’s in campus parking, shopping centers, or airport parking.

The parking monitoring sensors will help drivers find parking more easily and more efficiently, especially during busy mornings. Saving time is one of the aspects of the parking monitoring system to be able to find parking especially on crowded days.
In our specific case, NAVSEA is the sponsor for the project with their guidance and specifications. We were asked to implement the parking sensors monitoring on the campus. Furthermore, it is crucial to meet and exceed our customer’s expectations. Therefore, a beneficial approach for those wishing to benefit from the parking monitoring sensor is to develop an app that enables them to check parking availability. This step will help bridge the gap between customers and the project. Given the substantial impact this project will have on the campus community, our objective is to attract as many users as possible while ensuring the highest level of accuracy. The proposed parking monitoring system has the potential to make a positive impact on various stakeholders within the Tennessee Tech University community. It seeks to address a long-standing issue, enhance campus life, and bolster the university’s reputation for innovation and problem-solving. However, it is imperative to engage in careful planning and consider ethical and privacy implications thoroughly to ensure its successful implementation.
E. Current Solutions to Similar Problems
For many college campuses across America, parking is one of the biggest challenges that commuter students face daily. According to a survey by Mt. San Antonio College that included 1,033 responses, 68% of respondents state it takes 15 minutes or more to find a parking space with 32% stating it takes more than 30 minutes to find a space [3]. To solve this issue, the use of cameras or sensors to track the available parking would be a step in the right direction to help students know which areas of campus have available parking spaces. The following examples are just a few possible solutions to help college students find parking on campus.
- Parklio offers a product called Detect which is an intelligent AI system that monitors, analyzes, and reports vehicle parking data through the use of cameras while also generating a blueprint of the parking area it covers, creating a more accurate number of available parking spots for that specific area. One single camera has the ability to detect up to 200 vehicles at once, depending on the location and set up of the camera. The data received from the cameras go into a software called Parklio Parking Management System that provides real-time analytics for each camera in the system. [4]
- PlacePod provides sensors that can be placed either inground or surface-mounted sensors that communicate with a gateway to provide accurate vehicle detection in parking through a Low Power Wide Area Network (LPWAN). These sensors provide stable results even in harsh weather conditions while also having a battery life of up to 10 years. To communicate with the LPWAN, it includes a built in long range radio (LoRa radio) within the sensor. This product would be especially helpful in parking lots that are not close to buildings and may not have many light poles or power line poles near the parking lot to cover every spot.
- Currently, there are cameras that have the ability to detect the movement of vehicles. These cameras are primarily used for traffic flow measurement and automatic incident detection. With this type of system, the processing system for the camera is ”taught” the image of a vehicle through the use of measurements from the ground and the distance between lanes of vehicles. It has the ability to track numerous amounts of vehicles on one camera [3]. These types of cameras can cost anywhere from $250 or more depending on the options and the functions that come with the camera.
F. Need for Proposed Solution
As stated in previous sections of this proposal, parking is an extremely common challenge on many college campuses across the country, and unfortunately Tennessee Tech is not immune to this issue. Current solutions to similar problems do exist, however they can be very expensive, require significant maintenance efforts, and use proprietary software. Tennessee Tech would benefit from a student-made solution in the way of achieving a more cost-effective and custom solution. An inhouse solution would allow extensive customization to account for the unique problems campus parking may involve. An inhouse solution would also provide students with helpful data and could help ease some of the stress and frustration that currently comes with searching for a parking spot on campus. A student-made solution would also serve as a showcase of Tennessee Tech’s renowned engineering program. This project will involve the collaboration of engineering and computer science students, and is a great opportunity to show that Tennessee Tech engineers are renowned for good reason.

III. PROPOSED SOLUTION FOR PARKING LOT MONITORING SYSTEM
A. Solution Overview and Potential Approaches
1) Solution Set
a) This project’s scope is to be a proof of concept that can be scaled up to bigger parking lots and that can be applied to the majority of parking lots on campus. Our solution set includes parking lots that have designated entrances / exits and are only accessible through those entrances / exits, such as lots that are surrounded by curbs, sidewalks, or places that are not meant to be driven on. For example, stadium lot is one of the most indemand and large parking lots on campus. It has designated entrances and exits and the rest of the lot is bounded by curbs or sidewalks so it fits into our solution set.
2) Sensor Technology
a) A pneumatic tube system with low power consumption that observes spikes in pressure when force is applied to it. These sensors could be used as a ground based system to measure how many axles, and in turn how many vehicles, will be entering or exiting a given parking lot.
b) A weight sensor system observes a force applied to it and calculates the corresponding weight. Weight sensors could be used in a similar fashion to the pneumatic tubes as a ground based system to measure if a vehicle is entering or exiting a given parking lot.
c) Laser, lidar, and radar sensors all project a form of light or wave towards a target and, depending on the type, will receive the reflected light or wave. Any of these sensors could be used as an alternative to a ground based system to detect vehicles entering or exiting a parking lot. These sensors can, however, introduce problems with false detection of vehicles and adverse results with different weather conditions such as rain or abundant sunlight.
d) Camera or visual sensors would allow for the framing of visual images would could be processed to give information regarding the amount of empty parking spaces in a parking lot. The advantage of visual sensing is that the entire parking lot can be monitored compared to only entrances and exits.
3) Data Collection, Transportation, and Processing
a) Using any of the sensors mentioned above will require the transmission of the data they collect. For the ground based approach, the data will be collected at each entrance / exit of a given parking lot. For a visual approach, the data will be collected at the individual camera or sensor being used. The data will be transported wirelessly to a central processing unit that will communicate to and control the mobile application and sign. Wireless communication will simplify any future expansion of the system.
4) User Interface
a) A mobile application will display parking information. The students will be able to log in to the application using their student identification numbers and passwords. The app will display when the system is in operation, the amount of empty parking spaces in a parking lot.
b) A sign will be implemented that displays the total number of available parking spaces in a given parking lot.
c) Both the mobile application and sign will send out data to users during the hours of 8:00 a.m. to 4:30 p.m., which is when parking is enforced on campus. Data will still be collected outside these hours, but they will not be displayed on the sign nor the mobile application.
B. Unknowns and Obstacles

There are many unknowns and obstacles that may have am impact on our system such as the following:

- Illegal actions

– Vandalism of the system is an unknown. We can not guarantee our system will be safe from vandalism because it is essentially impossible to completely protect against all forms of vandalism. We do not know if this will be a problem, but it is a possibility. – Theft could occur if someone chooses to steal any part of the system. Attempts to make the system theft proof will not be able to completely stop a thief in all circumstances. It is unknown whether this is likely to happen.
– Illegal parking could affect the accuracy of our system. People may park in the grass or in a space that is not marked as a parking space. It is also possible that people could take up multiple spaces resulting in less accurate data.
- Weather

– Inclement weather could damage, disable, or in some way impede our system’s ability to function properly. – It is possible that inclement weather such as snow, heavy rain, or fog could affect the cameras’ ability to see. Strong wind, extreme cold, and lightning could possibly affect the sensors as well.

- Maintenance

– With any system comes the necessary maintenance in order to keep the system working correctly. If the system has an issue, then the issue can affect traffic on campus. If people are unable to park, they will drive around campus until they find a lot that has available parking. With numerous cars moving around campus, congestion is likely to occur causing the small issue that is occurring from the system to lead to larger problems such as possible vehicle incidents. In order to avoid these possible issues, the system needs to be designed and built to allow easy access of all components to make the maintenance process as simple as possible for those working on the system.
- Time Constraints

– Time constraints will limit the scope of the project to a proof of concept system that can be scaled up for use with bigger lots on campus. Time constraints will be handled by scheduling milestones for the project.

- Device Specifications

– Pneumatic road tube would need to be properly calibrated and regularly maintained, the extent to which is unknown. There must also be some way of distinguishing people walking over or jumping on the tubes from cars driving over them.

– Weight sensors would need to be properly calibrated and regularly maintained, the extent to which is unknown.
– Laser sensors would need to be properly calibrated and regularly maintained, the extent to which is unknown. There must also be some way of distinguishing people walking over or jumping on the tubes from cars driving over them.
– For a camera system, camera placement would be an obstacle as in some places there may not be enough conveniently-placed light poles to mount a camera.
- Infrastructure
– Installing sensors and signs will require the team to get approval from the Facilities and Parking departments.
- Accuracy
– The system will have an accuracy of at least 90%.
C. Measures of Success

To ensure the success of the proposed parking monitoring system, several key measures of success (MOEs) will need to be established. These MOEs will serve as benchmarks and criteria for evaluating the system’s effectiveness. Each MOE will be experimentally validated to ensure the system meets the specified constraints. It’s crucial to conduct these experiments to demonstrate the system’s reliability and functionality. The following MOEs are defined:
1) Accuracy of Parking Space Detection:
- Experiment: Select and monitor a small parking lot for a week period. Compare the system’s recorded data on parking lot availability with physical observation.
- Success Criteria: The system should maintain an accuracy rate of at least 90% in detecting the availability of parking spaces.
2) Reliability in Adverse Weather Conditions:
- Experiment: Subject the system to various weather conditions, including rain, snow, strong winds, and extreme cold, and assess its performance during adverse weather.
- Success Criteria: The system should continue to function with at least 90% accuracy during adverse weather conditions.
3) Real-Time Data Updates:
- Experiment: Continuously monitor and record the system’s update frequency for parking space availability over a one-week period.
- Success Criteria: The system should update parking availability data in real-time, with updates occurring at intervals no longer than 1 minute.
4) Detect Tampering and Sabotage for the system:
- Experiment: Evaluate the system’s ability to detect any tampering and sabotaging the system incidents.
- Success Criteria: The system should have a tamper detection rate of at least 90% and be designed to resist common forms of vandalism.
5) The Capability of Installing the System:
- Experiment: Evaluate the system’s capability to be installed within the campus parking lots by physically evaluating each parking suitable for the project. The suitable parking lots must have at least one entrance and exit.
- Success Criteria: The system should be suitable to cover the parking lots at Tennessee Tech University, accommodating at least 50% of the campus parking lots.
6) Safe Passage:
- Experiment: Evaluate the system with pedestrians navigating the campus parking lots without encountering safety hazards or disruptions caused by the parking monitoring system. Also, confirm that the parking monitoring system complies with accessibility regulations.
- Success Criteria: The system should have no impact on pedestrians and individuals with disabilities. The system should also not negatively affect driving on campus or hinder a driver’s ability to safely move around campus.
D. Broader Impacts/Ethics

With people using this system, their focus will be split in half as they focus on both the road in front of them and focus on the system as they find a lot with available parking. With their focus potentially being split in half, especially when traffic on campus is at an increased level, the risk of having a vehicle accident may increase. This impact may cause larger issues if the ease of access for the driver to use the system is not taken into consideration.
The main benefit of having a parking lot monitoring system that is easy to use by students, faculty, and visitors is that the amount of traffic on campus is able to decrease, even during peak hours. By reducing the traffic on campus, people will not have to search an entire lot to find available parking, but instead plan their route ahead of time to find parking in an efficient and timely manner without causing stress and anxiety, which could lead to major problems.

IV. RESOURCES AND REQUIREMENTS FOR IMPLEMENTATION

A. Resources

To implement and test this system, it will require the use of different hardware and software components, as listed below under Hardware and Software:
- Hardware
– Sensors that can detect the presence of vehicles
– Power supply to power the sensors used to detect vehicles

– Computer to test the system application to verify it functions correctly and to also code the system
- Software
– Programming software to use to program the sensors – Server to store data from the sensors to a database – Programming software that can control the application and receive information from the database
B. Personnel and Skills

Due to the extent of this project, it will be necessary to have two teams to continue this project from the last group: an Electrical and Computer Engineering team that will lead the project and continue the work of the last Electrical and Computer Engineering team and a Computer Science team that will implement an AI system into the project.

1) Electrical and Computer Engineering Team: The Electrical and Computer Engineering (ECE) team will be responsible for leading the two teams mentioned and continue the work of the last ECE team to work on this project. The group members of the ECE team brings a range of specialities from the fields of ECE. The team members of the ECE team are mentioned below along with their respective skills and experiences they bring to this project.
- Brady Beecham
– Programming Languages: C/C#/C++, Python, VHDL
– Software Skills: Object-Oriented Programming – Hard Skills: Soldering, Knowledge of electronic test equipment such as multimeters, oscilloscopes, etc.
– Engineering Experience: Co-op involving embedded software development
- Kyle Plant
– Programming Languages: Assembly, C/C++, VHDL, MATLAB, R, SQL, LISP, Bash, currently in the process of learning Python
– Software Skills: Microsoft Word, Microsoft Excel, AutoCAD, LTSpice, Git, Unix, Docker, Salt-Stack
– Hard Skills: Soldering, Arduino, Raspberry Pi, Electronics repair and troubleshooting, Reading controls schematics, Electrical circuit wiring.
– Engineering Experience:
∗ Internship at a chemical company involving database querying, statistical analysis of PLC data about gas purity and composition, GUI design.
∗ Internship at a chemical company IT department involving network administration, troubleshooting, hardware installation and setup ∗ Internship at an automation and system integration company as a Controls intern that involved making AutoCAD controls schematics for motor panels, conveyor device layouts, and I/O modules.
- Michael Sisk
– Programming Languages: C/C++, Assembly, MATLAB, R, Currently learning PLC Ladder Logic for Allen Bradley PLCs
– Software Skills: Microsoft Office, Google Drive, LTSpice, Microsoft Visual Studio, Currently learning Rockwell Automation Software Studio5000 and Rockwell Automation FactoryTalk Software for Allen Bradley PLCs
– Hard Skills: Soldering, Electronics repair and troubleshooting, Reading electrical schematics – Engineering Experience: Internship at a beverage company involving updating safety procedures for the company’s bottling facility. Obtained hands on experience installing and repairing electrical equipment such as electrical switches, induction motors, etc. and troubleshooting electrical equipment in the bottling facility under the supervision of the facility’s electricians.
- Khalifah Altamimi
– Programming Languages: C++, Assembly, MAT-LAB, R, Currently learning PLC Ladder Logic for Allen Bradley PLCs
– Software Skills: LTSpice, Visual Studio, Microsoft Office, Currently learning Rockwell Automation Software Studio5000 and Rockwell Automation FactoryTalk Software for Allen Bradley PLCs
– Hard Skills: Electronics repair and troubleshooting, Soldering, Reading controls schematics, Electrical circuit wiring
– Engineering Experience: Tutor and Grader for the Electrical and Computer Engineering Department at Tennessee Technological University
- Abdulrahman Alrudayan
– Programming Languages: C++, MATLAB, R, Currently learning PLC Ladder Logic for Allen Bradley PLCs
– Software Skills: LTSpice, Visual Studio, Microsoft Office.
– Hard Skills: Electronics repair and troubleshooting, Soldering, Reading controls schematics, Electrical circuit wiring
2) Partnerships: Our team will also being working together with a team from the Department of Computer Science. This team will focus in implementing artificial intelligence (AI) to the application software to use for future use and development of the system. Due to the background and knowledge of the ECE team members, the collaboration between the Department of Computer Science is instrumental in the continuous development of the system to help students find available parking in an efficient and timely manner.


Fig. 1. Expected Timeline

C. Budget
The cost of each parking lot will vary depending on the number of entrances and exits in the specific lot. The project is a proof of concept for a single lot that can be expanded to many lots. The single lot can have as many entrances / exits as we choose, with a likely choice of 2 or 3. We estimate the budget for an operational proof of concept range from $300-$500 for a lot with 2 or 3 entrances / exits.
D. Timeline
The group expects this project will be complete in nine months. Figure 1 shows the projected plan of progress for the project. At the beginning, specific ideas will be considered. As the project progresses, the group will create detailed designs of the system at the halfway point of the time-frame and end the project with experimentation and a product capable of helping people to find available parking in an efficient and timely manner.
V. CONCLUSION
A parking lot monitoring system that is designed and implemented on the campus of Tennessee Technological University would be beneficial in many ways to students who commute to campus daily and save students a few more minutes to get to their classes on time. By designing the system on campus, the system would be designed with the students in mind and the issues they currently face on the campus parking lots while also being cost-effective for the university. With the system being designed on campus, this will allow for a collaborative effort between the senior students of the Department of Electrical and Computer Engineering and the senior students of the Department of Computer Science to test both their knowledge and skills they have acquired over the course of their undergraduate education. To summarize, the design and implementation of a parking lot monitoring system on campus by students who face the same issues today will have numerous positive impacts for the Tennessee Tech community for many years to come.

REFERENCES

[1] Kesternucum, | “KESTERNUCUM/ECE-capstone-
team3: | Parking | lot | monitoring | system,” | GitHub,
https://github.com/kesternucum/ECE-Capstone-Team3/tree/main (accessed Sep. 13, 2023).
[2] “Tennessee tech grows total enrollment to more than
10,100 | students, | fueled | by | fourth | largest | freshman
class in university history,” Tennessee Tech University, https://www.tntech.edu/news/releases/22-23/tech-grows-totalenrollment-to-more-than-10100-students.php (accessed Sep. 13, 2023).
[3] Student survey on parking and desired parking structure location,, https://www.mtsac.edu/president/cabinet-notes/2016-17/PTK College 2016 Parking Student Survey.pdf (accessed Sep. 2, 2023).
[4] “ParklioTM detect - AI parking monitoring system,” Parklio Detect, https://parklio.com/en/parking-solutions/detect (accessed Sep. 2, 2023).
[5] Tbowman, “Video vehicle detection,” Cerritos College, https://www.cerritos.edu/auto/basic-its/vvd.htm (accessed Sep. 12, 2023).
[6] “NFPA 70 - National Electric Code,” National Fire Protection Agency. https://www.nfpa.org/codesand-standards/all-codesand-standards/list-of-codes-andstandards/detail?code=70. (accessed Sep. 12, 2023).
[7] “NFPA 70E - Standard for Electrical Safety in the Workplace,” National Fire Protection Agency. https://www.nfpa.org/codesand-standards/all-codes-andstandards/list-of-codes-and-standards/detail?code=70E (accessed Sep. 12, 2023).
[8] [1]“Browse Standards — Get Program — IEEE Xplore,” ieeexplore.ieee.org. https://ieeexplore.ieee.org/browse/standards/getprogram/page/series?id=68 (accessed Sep. 12, 2023).
[9] [1]14:00-17:00, | “ISO | 4414:2010,” | ISO.
https://www.iso.org/standard/44790.html (accessed Sep. 12, 2023).
[10] “Hands Free Tennessee,” Tennessee Highway Safety Office, 2021. https://www.handsfreetn.com. (accessed Sep. 12, 2023).

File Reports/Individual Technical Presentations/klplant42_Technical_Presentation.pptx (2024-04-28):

## LoRa


By Kyle Plant

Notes: Hello. This is my individual technical presentation for Capstone 2. I will be talking about LoRa.

## What is LoRa?

- Physical layer modulation technique
- Stands for Long Range
- Underlying modulation scheme behind LoRaWAN (Network layer)
- Operates at the 915 MHz ISM band in the US region
- Provides long range, low power consumption, low data rate, and affordable communication
  - Max range achieved: 1336 km / 830 miles (on the sea)
  - Data rates from 0.3 kbit/s to 27 kbit/s
- Great for IoT applications

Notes: First I should define what LoRa is. LoRa is a physical layer modulation technique. It stands for Long Range. LoRa is the physical layer modulation scheme behind the LoRaWAN network layer protocol. LoRa operates at different frequencies depending on your region but here in the US we use it at the 915 MHz ISM band. LoRa provides long range of course, low power consumption and low data rate relative to something like WiFi, and LoRa is very affordable, cheap devices can work with LoRa. Just some fun facts, the max range achieved by LoRa is 1336 km or 830 miles across the sea. And you can expect data rates from about 0.3 kbit/s to 27 kbit/s. These attributes make LoRa a great choice for IoT applications like transmitting sensor data every now and then.

## History of LoRa

- Invented in 2009 by Nicolas Sornin, Olivier Seller, and François Sforza. They founded Cycleo together.
- They were interested in the metering industry and aimed at adding wireless communication to gas, water, and electricity meters.
- They used Chirp Spread Spectrum modulation technology.
- CSS was already widely used for sonar and radar. Also, dolphins and bats use similar chirps to detect fish or insects!
- Cycleo however initiated the use of CSS for sending data.
- Cycleo acquired by Semtech in May 2012.
- Semtech with IBM created the LoRaMAC protocol.
- The LoRa Alliance was founded in 2015 and LoRaMAC was renamed LoRaWAN. Open, non-profit. Goal to promote adoption of LoRaWAN.

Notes: A little history lesson on LoRa.

## Benefits of LoRa

- Chirp Spread Spectrum modulation allows signal decoding when it’s completely sunk in noise. The ability to demodulate below the noise floor helps give the trademark long range of LoRa.
- Incredible range for how cheap it is to use.
- Low power usage.
- Widely used and supported for IoT. TTN, ChirpStack, etc.
- Computationally simple signal processing
- Flexibility, configurability

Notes: Some of the benefits of LoRa include its’ modulation technique, Chirp Spread spectrum modulation, which allows signal decoding when it’s completely sunk in noise. That ability to demodulate below the noise floor helps give LoRa its’ long range.

## Shortcomings of LoRa

- Data rate maxes out at around 27 kbit/s
- High latency

## LoRa Modulation

- Chirp Spread Spectrum Modulation.
  - A chirp is a signal where frequency increases or decreases with time.
  - CSS modulation takes the 1s and 0s of the data you want to send and converts them into a set of chirps made up of distinct symbols.
  - Up-chirps increase in frequency, down-chirps decrease.


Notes: Now, what is Chirp spread spectrum modulation? So first of all a chirp is..

## LoRa Frames

- Every line is a single chirp. The chirp sweeps over a range of frequencies over time.
- Preamble, sync word, data (and CRC).
- The Preamble and sync word get the attention of the receiver. They are easy to detect.
- Data is the part that is modulated. Frequency-time profile defines symbol value.


## LoRa Configuration

- Based on your application you can choose which balance of these are best for you.
- Need more range, more bandwidth, less time on air for saving battery power?
- Bandwidth
- Spreading Factor
- Coding Rate
- Data Rate, determined by the previous

## LoRa Configuration - Bandwidth

- The rate a signal changes. Defines the maximum amount of information that can be communicated per unit of time.
- Uses units: Hz
- Commonly used bandwidths are 125 kHz, 250 kHz, and 500 kHz.
- High quality radios with TCXOs can get even lower for extreme range. As low as 7.8 kHz.
- Rule of thumb:
  - The higher the bandwidth, the higher the data rate.
  - The lower the bandwidth, the lower the data rate.

## LoRa Configuration – Spreading Factor

- The ratio between the bandwidth and the data rate.
- Commonly used SFs are SF7 to SF12
- Determines the speed at which the chirp is swept across the frequency range.
- Affects time on air.
  - Higher SF, higher time on air, consequently more power draw, vice versa.
- Higher spreading factors help increase the range because they can be demodulated further below the noise floor than lower spreading factors.
- Increasing the SF by 1 halves data rate for fixed bandwidth, vice versa.

## LoRa Configuration – Spreading Factor


## LoRa Configuration – Coding Rate

- Defines the efficiency of error-correcting codes.
- Represented by a ratio of the information bits to the total number of bits transmitted.
- Commonly set to 4/5 because LoRaWAN fixes the coding rate to 4/5.
- The redundant bits allow the receiver to recover from demodulation errors.
- CRC – cyclic redundancy check.
- Higher number of redundant bits, lower data rate, and higher resiliency to errors, vice versa.

## LoRa Configuration - Summary


From: https://www.lab5e.com/docs/lora/dr_sf/

## LoRa Frame MATLAB example

- There is a great MATLAB script that can generate LoRa frames and display them on a spectrogram!
- Credit: B. Al Homssi, K. Dakic, S. Maselli, H. Wolf, S. Kandeepan, and A. Al-Hourani, "IoT Network Design using Open-Source LoRa Coverage Emulator," in IEEE Access. 2021.

## LoRa Frame MATLAB example


## Math Underlying LoRa CSS Modulation - Symbols


- Where SF is Spreading Factor (7-12)
- The number of symbols is 2SF
- So the symbols are S = 0, 1, 2 … 2SF-1
- SF means bits per symbol, ex. SF7 has 7 bits per symbol
- From Euler’s relation, cos is real sin is imaginary.
- General expression for a chirp’s instantaneous frequency where Phase is θ , Frequency is ω=2πf , and Chirp rate is μ :
  - x(t)=e^(j(πμ^2 +2πft+θ))

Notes: The chirp is complex at baseband

## Math Underlying LoRa CSS Modulation - Symbols

- How to form each symbol:
  - Where s is the symbol number (like the starting point of the chirp), Ts is the symbol duration, T is the sample duration, SF is spreading factor, k increments on each sample, it is a frequency. Modulo rolls the instantaneous frequency roll back to the lowest frequency when the bandwidth limit 2^(SF) is reached, produces discontinuity you can see in the chirp spectrographs.
  - End frequency of a chirp will be the same as the start frequency.
  - c(nT_s +kT)= 1/(√(2^(SF)))e^(j2π((s(nT_s ))+k)mod 2^(SF) )k/(2^(SF)))

## Math underlying LoRa CSS Modulation - Demodulation

- The receiver will get the strength of similarity of the received signal to each of the known basis symbols (r) and multiply that by a downchirp. Known as dechirping.
- Then perform the correlation with the bank of frequencies that depend on s. Equivalent to FFT. Find max correlation to determine symbol.


## MATLAB Example: https://www.youtube.com/watch?v=jHWepP1ZWTk


## Thank You!

## References

- LoRa world record: https://www.thethingsnetwork.org/article/new-lora-world-record-1336-km-830-mi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,on%20the%20Sesimbra%20coast%2C%20Portugal.
- LoRa History: https://blog.semtech.com/a-brief-history-of-lora-three-inventors-share-their-personal-story-at-the-things-conference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,the%20idea%20into%20a%20reality.
- MatLab code: B. Al Homssi, K. Dakic, S. Maselli, H. Wolf, S. Kandeepan, and A. Al-Hourani, "IoT Network Design using Open-Source LoRa Coverage Emulator," in IEEE Access. 2021. Link on IEEE: https://ieeexplore.ieee.org/document/9395074 Link on researchgate: https://www.researchgate.net/publication/350581481_IoT_Network_Design_using_Open-Source_LoRa_Coverage_Emulator

## References

- https://wirelesspi.com/understanding-lora-phy-long-range-physical-layer/
- https://www.youtube.com/watch?v=jHWepP1ZWTk
- L. Vangelista, "Frequency Shift Chirp Modulation: The LoRa Modulation," in IEEE Signal Processing Letters, vol. 24, no. 12, pp. 1818-1821, Dec. 2017, doi: 10.1109/LSP.2017.2762960.

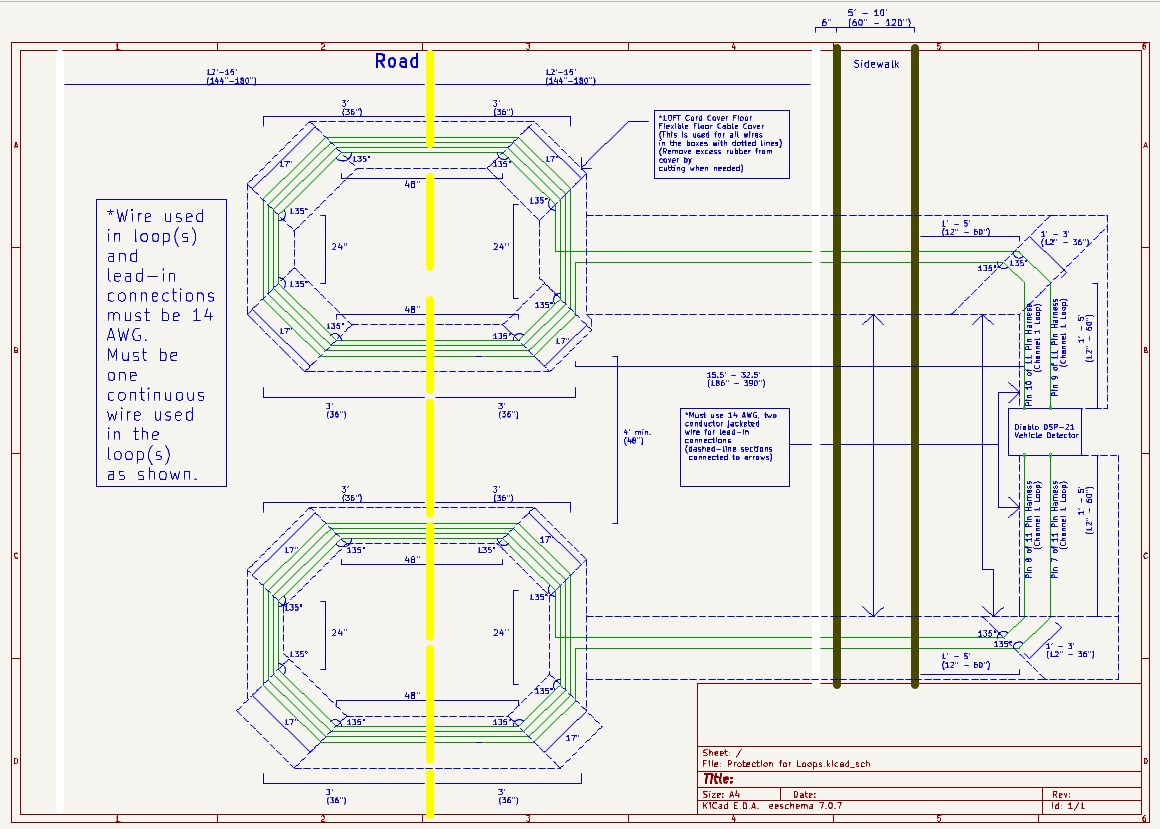
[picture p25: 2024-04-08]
Documentation/Images/Inductive Loops.jpg

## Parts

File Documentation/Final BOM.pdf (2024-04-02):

Part Number | Description | Manufacturer | Quantity Cost per Item Total Cost of Quantity | Subsystem Used
LT3120JV#PBF | Switching Voltage Regulators 26V, 9A Low-IQ CC/CV Monolithic Buck-Boost Converter | Analog Devices | 1 | $10.04 | $10.04 | Charge Controller
LTC4020EUHF#PBF | Battery Management 55V Buck-Boost Multi-Chemistry Battery Charger | Analog Devices | 1 | $12.51 | $12.51 | Charge Controller
TPS61170DRVR | Switching Voltage Regulators 1.2A Sw Hi Vltg Boost Conv | Texas Instruments | 1 | $1.94 | $1.94 | Charge Controller
ACS712ELCTR-05B-T | Board Mount Current Sensors For New Designs Use ACS724/5 | Allegro MicroSystems | 1 | $3.70 | $3.70 | Charge Controller
TLV9361QDCKRQ1 | Operational Amplifiers - Op Amps Automotive, single, 40-V 10.6-MHz rail-to-rail output operational amplifier 5-SC70 -40 to 125 Texas Instruments | 1 | $1.51 | $1.51 | Charge Controller
G6RN-1-DC5 | General Purpose Relays Heavy-Duty SPDT 5VDC | Omron Electronics | 2 | $4.10 | $8.20 | Charge Controller
SI7272DP-T1-GE3 | MOSFET 30V Vds 20V Vgs PowerPAK SO-8 | Vishay Semiconductors | 4 | $1.43 | $5.72 | Charge Controller
NVD5117PLT4G-VF01 | MOSFET PFET DPAK 60V 61A 16MOHM | onsemi | 2 | $1.97 | $3.94 | Charge Controller
SBR0560S1Q-7 | Schottky Diodes & Rectifiers SBR Diode | Diodes Incorporated | 5 | $0.38 | $1.90 | Charge Controller
BZX84C6V2LT116 | Zener Diodes BZX84C6V2L is Zener Diode for voltage regulation. | ROHM Semiconductor | 2 | $0.24 | $0.48 | Charge Controller
RFN10BM3STL | Diodes - General Purpose, Power, Switching 350V Vrm 10A Io Std Fast Rec Diode | ROHM Semiconductor | 2 | $1.27 | $2.54 | Charge Controller
PA4339.701NLT | Common Mode Chokes / Filters CMC 5.0uH 4A | Pulse Electronics | 2 | $1.77 | $3.54 | Charge Controller
SRP1245CC-150M | Power Inductors - SMD Ind,13.5x12.5x4.8mm,15uH+/-20%,9A,shd | Bourns | 2 | $1.96 | $3.92 | Charge Controller
12062A500KAT2A | Multilayer Ceramic Capacitors MLCC - SMD/SMT 200V 50pF C0G 1206 10% | KYOCERA AVX | 2 | $0.41 | $0.82 | Charge Controller
KGM31BCG1H101JT | Multilayer Ceramic Capacitors MLCC - SMD/SMT 50V 100pF C0G 1206 5% | KYOCERA AVX | 2 | $0.24 | $0.48 | Charge Controller
KGM31TCG2H681JU | Multilayer Ceramic Capacitors MLCC - SMD/SMT 500V 680pF C0G 1206 5% | KYOCERA AVX | 3 | $0.28 | $0.84 | Charge Controller
KGM31AR73D102KU | Multilayer Ceramic Capacitors MLCC - SMD/SMT 2000V .001uF X7R 1206 10% | KYOCERA AVX | 2 | $0.71 | $1.42 | Charge Controller
30LVD40-R | Safety Capacitors .25LS 4000PF 300V 20% | Vishay | 2 | $1.66 | $3.32 | Charge Controller
KAM31GCG2J103JU | Multilayer Ceramic Capacitors MLCC - SMD/SMT 630V 10,000pF C0G 1206 5% AEC-Q200 | KYOCERA AVX | 2 | $0.99 | $1.98 | Charge Controller
KGM31BR71H223JT | Multilayer Ceramic Capacitors MLCC - SMD/SMT 50V .022uF X7R 1206 5% | KYOCERA AVX | 2 | $0.31 | $0.62 | Charge Controller
C1206C683J5GECAUTO7210 Multilayer Ceramic Capacitors MLCC - SMD/SMT 50V 0.068uF C0G 1206 5% AEC-Q200 | KEMET | 2 | $0.74 | $1.48 | Charge Controller
KGM31BR71H104JT | Multilayer Ceramic Capacitors MLCC - SMD/SMT 50V .1uF X7R 1206 5% | KYOCERA AVX | 5 | $0.30 | $1.50 | Charge Controller
KAF31BR71H224KT | Multilayer Ceramic Capacitors MLCC - SMD/SMT 50V .22uF X7R 1206 10% AEC-Q200 FLEXITERM | KYOCERA AVX | 3 | $0.44 | $1.32 | Charge Controller
KAM31NR81H334KU | Multilayer Ceramic Capacitors MLCC - SMD/SMT 50V .33uF X8R 1206 10% AEC-Q200 | KYOCERA AVX | 2 | $0.40 | $0.80 | Charge Controller
KGM31HR71E105KU | Multilayer Ceramic Capacitors MLCC - SMD/SMT 25V 1uF X7R 1206 10% | KYOCERA AVX | 3 | $0.33 | $0.99 | Charge Controller
KAF31GR71E225KU | Multilayer Ceramic Capacitors MLCC - SMD/SMT 25V 2.2uF X7R 1206 10% AEC-Q200 FLEXITERM | KYOCERA AVX | 2 | $0.42 | $0.84 | Charge Controller
TE1202-E3 | Aluminum Electrolytic Capacitors - Axial Leaded 25V 5uF | Vishay | 4 | $4.25 | $17.00 | Charge Controller
870575873001 | Aluminum Organic Polymer Capacitors WCAP-HTG5 63V 10uF 20% THT Radial -55/+105C | Wurth Elektronik | 5 | $1.33 | $6.65 | Charge Controller
C3216X5R1V156M160AC | Multilayer Ceramic Capacitors MLCC - SMD/SMT 1206 35V 15uF X5R 20% T: 1.6mm | TDK | 3 | $0.89 | $2.67 | Charge Controller
C3216X5R0J686M160AB | Multilayer Ceramic Capacitors MLCC - SMD/SMT 1206 6.3V 68uF X5R 20% T: 1.6mm | TDK | 2 | $0.78 | $1.56 | Charge Controller
870575574002 | Aluminum Organic Polymer Capacitors WCAP-HTG5 25V 150uF 20% THT Radial -55/+105C | Wurth Elektronik | 2 | $1.81 | $3.62 | Charge Controller
WSL2512R0140FEA18 | Current Sense Resistors - SMD 2watts .014ohm 1% | Vishay / Dale | 4 | $1.11 | $4.44 | Charge Controller
SFR18EZPF1000 | Thick Film Resistors - SMD Sulfur Tolerant Chip Resistor | ROHM Semiconductor | 3 | $0.26 | $0.78 | Charge Controller
CCF073K60JKE36 | Metal Film Resistors - Through Hole CCF-07 3.6K 5% T-1 E36 e3 | Vishay / Dale | 2 | $0.30 | $0.60 | Charge Controller
ROX7J10K | Metal Oxide Resistors 7W STD M/OX 5% 10K | TE Connectivity / Holsworthy 7 | $1.04 | $7.28 | Charge Controller
ERA-8AEB1402V | Thin Film Resistors - SMD 1206 14Kohm 25ppm 0.1% AEC-Q200 | Panasonic | 2 | $0.59 | $1.18 | Charge Controller
MFR-12FTF52-17K | Metal Film Resistors - Through Hole | YAGEO | 2 | $0.10 | $0.20 | Charge Controller
3503G2B20KFTDF | Thin Film Resistors - SMD 3503G 2B 20K 1% 1K RL | TE Connectivity / Holsworthy 3 | $1.67 | $5.01 | Charge Controller
CRCW251230K0JNEG | Thick Film Resistors - SMD 1watt 30Kohms 5% | Vishay / Dale | 2 | $0.32 | $0.64 | Charge Controller
ROX7J33K | Metal Oxide Resistors 7W STD M/OX 5% 33K | TE Connectivity / Holsworthy 3 | $1.33 | $3.99 | Charge Controller
CCF5576K8FKE36 | Metal Film Resistors - Through Hole 1/4watt 76.8Kohms 1% Rated to 1/2watt | Vishay / Dale | 2 | $0.30 | $0.60 | Charge Controller
ROX9J100K | Metal Oxide Resistors 9W STD M/OX 5% 100K | TE Connectivity / Holsworthy | 5 | $1.30 | $6.50 | Charge Controller
ERA-8KEB1203V | Thin Film Resistors - SMD 1206 Thin film res high stability type | Panasonic | 2 | $0.82 | $1.64 | Charge Controller
CRCW2512140KFKEG | Thick Film Resistors - SMD 1 watt 140Kohms 1% 100ppm | Vishay / Dale | 2 | $0.34 | $0.68 | Charge Controller
ERA-8KEB2703V | Thin Film Resistors - SMD 1206 Thin film res high stability type | Panasonic | 2 | $0.82 | $1.64 | Charge Controller
CRCW2512620KJNEG | Thick Film Resistors - SMD 620K OHM 5% | Vishay / Dale | 2 | $0.36 | $0.72 | Charge Controller
RCV12062M00FKEAAT | Thick Film Resistors - SMD RCV1206-AT 100 2M0 1% ET1 E3 | Vishay | 2 | $0.35 | $0.70 | Charge Controller
| TE Connectivity, Buchanan 2.54mm Pitch, 2 Way PCB Terminal Strip | TE Connectivity | 12 | $1.41 | $16.92 | Charge Controller
ESP32-DEVKITC-32E | ESP32-WROOM-32E 4MB FLASH | Espressif Systems | 2 | $10.00 | $20.00 | Data Management
3072 | RFM95W LORA RADIO TRANSCEIVER BR | Adafruit Industries LLC | 2 | $19.95 | $39.90 | Data Management
IPXSM66AL (I-PEX P/N 20279-001E-03) I-PEX (MHF1) SMD RECEPTACLE | Lighthorse Technologies, Inc 2 | $0.75 | $1.50 | Data Management
TY-CSA23 | 915MHz LoRa Antenna Omni 5dbi SMA Male + 15cm IPEX Extension Cable 2 Pcs | Tenmory | 1 | $13.99 | $13.99 | Data Management
N/A, Seeed Studio SKU: 110991765 Long Range Indoor Antenna Kit; 860-930MHz; 3dBi; 295mm | Seeed Studio | 1 | $14.90 | $14.90 | Data Management
N/A, ASIN: B07T85B3LN | Tenmory UFL to SMA Mini PCI U.FL to RP-SMA Female Ipex Connector Pigtail Antenna Extension Cable (6 Tenmory | 1 | $5.99 | $5.99 | Data Management
N/A, Seeed Studio SKU: 113100022 WM1302 Raspberry Pi Hat | Seeed Studio | 1 | $19.90 | $19.90 | Data Management
WM1302-USB-US915-M | WM1302 LoRaWAN Gateway Module (USB) - US915 | Seeed Studio | 1 | $29.00 | $29.00 | Data Management

SDSQUA4-064G-GN6MA | SanDisk 64GB Ultra microSDHC | SanDisk | 1 | $9.81 | $9.81 | Data Management
ASIN: B07TC2BK1X, Model #: RAS-4-4G Raspberry Pi 4 Model B 2019 (4GB) | Raspberry Pi Foundation | 1 | $61.49 | $61.49 | Data Management
ASIN: B07TYQRXTK | CanaKit 3.5A Raspberry Pi 4 Power Supply (USB-C) | CanaKit | 1 | $9.99 | $9.99 | Data Management
ASIN: B00507GV38, Model #: 107603 Monoprice 6inch HDMI Micro Connector male to HDMI Connector female - Black | Monoprice | 1 | $4.98 | $4.98 | Data Management
94-200-060 BK | 60 ft. Electrical Tape | Duck Brand | 1 | $1.23 | $1.23 | Inductive Loop
1265013 | 20 yd Duck Tape Yellow | Duck Brand | 1 | $3.94 | $3.94 | Inductive Loop
14 AWG Wire | 14 AWG Wire to | N/A | 485 ft | $0.00 | 0 | Inductive Loop
R82DC3220AA60K | CAPACITOR | KEMET | 2 | $0.30 | $0.60 | Loop Controller
K104K10X7RF53L2 | Capacitor | Vishay/BC Components | 4 | $0.17 | $0.68 | Loop Controller
UVR1H102MHD | Polarized Capacitor | Nichicon | 12 | $0.98 | $11.76 | Loop Controller
MFR-25FTF52-100K | Resistor | YAGEO | 4 | $0.10 | $0.40 | Loop Controller
MFR-25FTF52-100R | Resistor | YAGEO | 8 | $0.10 | $0.80 | Loop Controller
CF14JT220R | Resistor | Stackpole Electronics Inc. | 4 | $0.10 | $0.40 | Loop Controller
2N3904 | NPN Transistor | Diotec Semiconductor | 4 | $0.13 | $0.52 | Loop Controller
B82731T2301A020 | Inductor | EPCOS/TDK | 2 | $2.72 | $5.44 | Loop Controller
C322C106K3R5TA | Capacitor | KEMET | 4 | $0.79 | $3.16 | Loop Controller
MFR-25FTE52-33K | Resistor | YAGEO | 4 | $0.10 | $0.40 | Loop Controller
MFR-25FTF52-10K | Resistor | YAGEO | 16 | $0.10 | $1.60 | Loop Controller
MFR-25FRF52-3K3 | Resistor | YAGEO | 4 | $0.10 | $0.40 | Loop Controller
MFR-25FTE52-330K | Resistor | YAGEO | 4 | $0.10 | $0.40 | Loop Controller
LT1720CS8#PBF | Comparator | Analog Devices Inc. | 2 | $10.24 | $20.48 | Loop Controller
1711026 | Phoenix Fixed Terminal Block | Phoenix Contact | 2 | $2.02 | $4.04 | Loop Controller
1905201 | Phoenix Fixed Terminal Block | Phoenix Contact | 2 | $4.55 | $9.10 | Loop Controller
L78L33ABZ-AP | Linear Voltage Regulator | STMicroelectronics | 2 | $0.36 | $0.72 | Loop Controller
| PCB Board | JLCPCB | 5 | | $0.00 | Loop Controller
LTC3621IMS8E#PBF | Step down buck regulator : Conv DC-DC 2.7V to 17V Synchronous Step Down Single-Out 0.6V to 17V 1A Automotive 8-Pin MSOP EP Tube Analog Devices | 3 | $8.12 | $24.36 | Power Controller
ERJ-1GNF1963C | Resistor 196k : Thick Film Chip Resistor, 0201, 0.05W | Panasonic | 3 | $0.10 | $0.30 | Power Controller
ERJ-1GNF2402C | Resistor 24k : PANASONIC ELECTRONIC COMPONENTS - ERJ1GNF2402C - RES, THICK FILM, 24K, 1%, 0.05W, 0201 Panasonic | 3 | $0.10 | $0.30 | Power Controller
ERJ-1GNF1402C | Resistor 14k : PANASONIC - ERJ1GNF1402C - SMD Chip Resistor, 0201 [0603 Metric], 14 kohm, ERJ1GN Series, 25 V, Thick Film, 50 mW Panasonic | 3 | $0.10 | $0.30 | Power Controller
XFL3012-153MEC | Inductor 15uH : Power Inductors - SMD 15Uh Shld 1A 483mOhms AECQ2 | Coilcraft | 2 | $2.08 | $4.16 | Power Controller
MSS7348-683MEC | Inductor 68uH : Fixed Inductors 68uH Shld 20% 1.2A 225mOhms | Coilcraft | 1 | $2.62 | $2.62 | Power Controller
C3216CH2J221J060AA | Capacitor 22pF : MULTILAYER CERAMIC CHIP CAPACITORS, 3216, Commercial grade, general (Up to 75V) TDK | 3 | $0.21 | $0.63 | Power Controller
C3216X8R1E105M160AA | Capacitor 1uF : MULTILAYER CERAMIC CHIP CAPACITORS, 3216, Commercial grade, general (Up to 75V) | TDK | 3 | $0.42 | $1.26 | Power Controller
C3216JB1E106M160AB | Capacitor 10uF : MULTILAYER CERAMIC CHIP CAPACITORS, 3216, Commercial grade, general (Up to 75V) TDK | 3 | $0.56 | $1.68 | Power Controller
C3216JB1C226M160AB | Capacitor 22uF : MULTILAYER CERAMIC CHIP CAPACITORS, 3216, Commercial grade, general (Up to 75V) TDK | 3 | $0.64 | $1.92 | Power Controller
282834-2 | TE Connectivity, Buchanan 2.54mm Pitch, 2 Way PCB Terminal Strip | TE Connectivity | 4 | $1.41 | $5.64 | Power Controller
NPA30S-12I | Newpowa 9BB 30W 12V Solar Panel High-Efficiency Monocrystalline 12V PV Module Designed for 12V Off Grid System, Charge Your 12V Battery of RV, Boat, Camper, Trailer, Gate Opener(30W New) Newpowa | 1 | $44.79 | $44.79 | Solar Power
ML12-12 | ML12-12F2 - 12 Volt 12 AH | F2 Terminal | Rechargeable SLA AGM Battery | Mighty Max Battery | 2 | $27.99 | $55.98 | Solar Power
B01CWYFS4Y | 10 Pairs Red Ultra T Plug Connectors Deans Style For RC LiPo Battery Male and Female + (20 Pack) Shrink Tubing WST | 1 | $7.29 | $7.29 | Solar Power
B08CZ7Z9TB | Adapter Power Supply"12V 3A Adapter Power Supply AC to DC Plug" | LitStar | 1 | $9.99 | $9.99 | Wall Power
LTC3621 | Step down "Buck Converter" | Analog
| | Devices | 2 | $8.12 | $16.24 | Wall Power
EXP1218 | Battery: xpert Power Sealed Lead Acid Batteries | ExpertPower | 1 | $34.40 | $34.40 | Wall Power
G6RN-1-DC5 | Switch: General Purpose Relays Heavy-Duty SPDT 5VDC | Omron
| | Electronics (https://www.digikey.com/en/products/filter/power-relays-over-2-amps/omron-electronics-inc-emc-div/188) | 1 | $4.10 | $4.10 | Wall Power
XFL3012-153MEC | Inductor 15uH Power Inductors SMD 15Uh Shld 1A 483mOhms AECQ2 | Coilcraft | 1 | $2.08 | $2.08 | Wall Power
MSS7348-683MEC | Inductor 68uH :Power Inductors SMD 68uH Shld 20% 1.2A 225mOhms | Coilcraft | 1 | $2.62 | $2.62 | Wall Power
CRGH2512J82K | resistor 82k: Thick Film Resistors - SMD CRGH2512 5% 82K 2W | pansonic | 1 | $0.65 | $0.65 | Wall Power
CRGH2512J82K | resistor 10k:Thick Film Resistors - SMD CRG0603 5% 10K | pansonic | 1 | $0.65 | $0.65 | Wall Power
ERJ-P08F9532V resistor 95.3k:Thick Film Resistors SMD 0201 95.3Kohm 1% HalogenFree AEC-Q2000.66W 1% AEC-Q200 pansonic 1 | $0.28 | $0.28 Wall Power
resistor 6.8k: Thick Film Resistors SMD 3521 6K8 1% 2W TE Connectivity 35216K8FT Holsworthy (https://www.mouser.com/manufacturer/te-holsworthy/) 1 | $0.51 | $0.51 Wall Power

C2220C204KBG
LCAUTO

capacitor 200uF: Multilayer Ceramic Capacitors MLCC - SMD/SMT 630Vo 0.2uF 2220 C0G w/KONNEKT AECQ2

KEMET (https://www.mouser.com/manufacturer/kemet-electronics/) | 1 | $4.37 | $4.37 | Wall Power

C3216JB1E106
M160AB

capacitor 10uF: Multilayer Ceramic Capacitors MLCC - SMD/SMT RECOMMENDED ALT 810-C3216X5R1E106K

TDK | 2 | $0.59 | $1.18 | Wall Power

KAM15AR72
A103KM
capacitor 10nF: Multilayer Ceramic Capacitors MLCC SMD/SMT 100V 10,000pF X7R 0603 10% AECQ200 | KYOCERA
AVX (https://www.mouser.com/manufacturer/kyocera-avx/) | 1 | $0.31 | $0.31 | Wall Power

C3216X8R1E105M1
60AA

capacitor 1uF: Multilayer Ceramic Capacitors MLCC SMD/SMT RECOMMENDED ALT 810-C3216X8R1E105K TDK (https://www.mouser.com/manufacturer/tdk/)
2 | $0.42 | $0.84 | Wall Power

C3216CH2J221J06
0AA

capacitor 22pF: Multilayer Ceramic
Capacitors MLCC - SMD/SMT RECOMMENDED ALT 810-C3216C0G2J221J

TDK
2 | $0.23 | $0.46 | Wall Power

C3216JB1C226M16
0AB

capacitor 22uF:Multilayer
Ceramic Capacitors MLCC
SMD/SMT RECOMMENDED ALT
810-C3216X5R1C226M

TDK

2 | $0.86
| | $1.72 | Wall Power
Total | 289 | $690.52

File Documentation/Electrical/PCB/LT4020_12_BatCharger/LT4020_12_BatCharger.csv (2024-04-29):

Source: | C:\Users\Bkb61\OneDrive\Documents\School_Work\Capstone\ChargeController\LT4020_12_BatCharger\LT4020_12_BatCharger.kicad_sch
Date: | 2/14/2024 2:34:27 PM
Tool: | Eeschema 7.0.8
Generator: | C:\Program Files\KiCad\7.0\bin\scripting\plugins/bom_csv_grouped_by_value.py
Component Count: | 38
Collated Components:
Item | Qty | Reference(s) | Value | LibPart | Footprint | Datasheet | DNP | Arrow Part Number | Arrow Price/Stock | Height | Manufacturer_Name | Manufacturer_Part_Number | Mouser Part Number | Mouser Price/Stock | Sim.Device | Sim.Pins | Sim.Type
1 | 2 | C_BST1, C_BST2 | 1u | Device:C | Capacitor_SMD:C_1206_3216Metric_Pad1.33x1.80mm_HandSolder | ~
2 | 1 | C_CSN1 | 0.33u | Device:C | Capacitor_SMD:C_1206_3216Metric_Pad1.33x1.80mm_HandSolder | ~
3 | 1 | C_CSOUT1 | 100p | Device:C | Capacitor_SMD:C_1206_3216Metric_Pad1.33x1.80mm_HandSolder | ~
4 | 2 | C_IN1, C_OUT1 | 0.1u | Device:C_Polarized | Capacitor_SMD:C_1206_3216Metric_Pad1.33x1.80mm_HandSolder | ~
5 | 2 | C_IN2, C_IN3 | 15u | Device:C | Capacitor_SMD:C_1206_3216Metric_Pad1.33x1.80mm_HandSolder | ~
6 | 1 | C_intvcc1 | 2.2u | Device:C | Capacitor_SMD:C_1206_3216Metric_Pad1.33x1.80mm_HandSolder | ~
7 | 1 | C_OUT2 | 68u | Device:C | Capacitor_SMD:C_1206_3216Metric_Pad1.33x1.80mm_HandSolder | ~
8 | 1 | C_pvin1 | 10u | Device:C | BatChargerFootprints:CAPPRD250W65D630H900 | ~
9 | 1 | C_senseB1 | 68n | Device:C | Capacitor_SMD:C_1206_3216Metric_Pad1.33x1.80mm_HandSolder | ~
10 | 1 | C_VC1 | 680p | Device:C | Capacitor_SMD:C_1206_3216Metric_Pad1.33x1.80mm_HandSolder | ~
11 | 3 | D1, D2, D3 | SBR0560S1Q-7 | BatChargerSymbols:SBR0560S1Q-7 | BatChargerFootprints:SOD3716X145N | https://www.arrow.com/en/products/sbr0560s1q-7/diodes-incorporated |  | SBR0560S1Q-7 | https://www.arrow.com/en/products/sbr0560s1q-7/diodes-incorporated?region=nac | 1.45 | Diodes Incorporated | SBR0560S1Q-7 | 621-SBR0560S1Q-7 | https://www.mouser.co.uk/ProductDetail/Diodes-Incorporated/SBR0560S1Q-7?qs=4EhzHfbM1GiCOHzHUGtr2w%3D%3D
12 | 1 | FL1 | PA4339.701NLT | BatChargerSymbols:PA4339.701NLT | BatChargerFootprints:PA4339701NLT | https://componentsearchengine.com/Datasheets/1/PA4339.701NLT.pdf |  | PA4339.701NLT | https://www.arrow.com/en/products/pa4339.701nlt/pulse-electronics-corporation?region=nac | 3.8 | Pulse Electronics | PA4339.701NLT | 673-PA4339.701NLT | https://www.mouser.co.uk/ProductDetail/Pulse-Electronics/PA4339.701NLT?qs=byeeYqUIh0MubUfGghqscg%3D%3D
13 | 4 | H1, H2, H3, H4 | MountingHole | Mechanical:MountingHole | MountingHole:MountingHole_2.2mm_M2 | ~
14 | 1 | IC1 | LTC4020EUHF#PBF | BatChargerSymbols:LTC4020EUHF#PBF | BatChargerFootprints:QFN50P500X700X80-39N-D | http://cds.linear.com/docs/en/datasheet/4020fd.pdf |  | LTC4020EUHF#PBF | https://www.arrow.com/en/products/ltc4020euhfpbf/analog-devices?region=nac | 0.8 | Analog Devices | LTC4020EUHF#PBF | N/A | https://www.mouser.com/Search/Refine.aspx?Keyword=N%2FA
15 | 1 | J1 | ChargeController_Main | Connector:Screw_Terminal_01x06 | Connector_Wire:SolderWire-1sqmm_1x06_P7.8mm_D1.4mm_OD3.9mm | ~
16 | 1 | Q1 | PMOS | Simulation_SPICE:PMOS | BatChargerFootprints:NVD5117PLT4GVF01 | https://ngspice.sourceforge.io/docs/ngspice-manual.pdf |  |  |  |  |  |  |  |  | PMOS | 1=D 2=G 3=S | VDMOS
17 | 2 | Q2, Q3 | SI7272DP-T1-GE3 | BatChargerSymbols:SI7272DP-T1-GE3 | BatChargerFootprints:SI7288DPT1GE3 | https://www.vishay.com/docs/69026/si7272dp.pdf |  | SI7272DP-T1-GE3 | https://www.arrow.com/en/products/si7272dp-t1-ge3/vishay |  | Vishay | SI7272DP-T1-GE3 | 781-SI7272DP-GE3 | https://www.mouser.com/Search/Refine.aspx?Keyword=781-SI7272DP-GE3
18 | 3 | R_CS1, R_SENSEA1, R_SENSEB1 | 0.014 | Device:R | Resistor_SMD:R_1206_3216Metric_Pad1.30x1.75mm_HandSolder | ~
19 | 2 | R_CSN1, R_CSP1 | 100 | Device:R | Resistor_SMD:R_1206_3216Metric_Pad1.30x1.75mm_HandSolder | ~
20 | 2 | R_FB1, R_FBMAX_2 | 98.8k | Device:R | Resistor_SMD:R_1206_3216Metric_Pad1.30x1.75mm_HandSolder | ~
21 | 2 | R_FB2, R_FBMAX_1 | 20k | Device:R | Resistor_SMD:R_1206_3216Metric_Pad1.30x1.75mm_HandSolder | ~
22 | 1 | R_RT1 | 270k | Device:R | Resistor_SMD:R_1206_3216Metric_Pad1.30x1.75mm_HandSolder | ~
23 | 1 | R_VC1 | 33k | Device:R | Resistor_THT:R_Axial_DIN0309_L9.0mm_D3.2mm_P5.08mm_Vertical | ~
24 | 1 | Z1 | BZX84C6V2LT116 | BatChargerSymbols:BZX84C6V2LT116 | BatChargerFootprints:SOT95P240X115-3N | https://fscdn.rohm.com/en/products/databook/datasheet/discrete/diode/zener/bzx84c6v2lt116-e.pdf |  |  |  | 1.15 | ROHM Semiconductor | BZX84C6V2LT116 | 755-BZX84C6V2LT116 | https://www.mouser.co.uk/ProductDetail/ROHM-Semiconductor/BZX84C6V2LT116?qs=4v%252BiZTmLVHH7p%2FgGW5uwkw%3D%3D

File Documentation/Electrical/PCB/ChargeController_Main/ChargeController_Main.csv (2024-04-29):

Source: | C:\Users\Bkb61\OneDrive\Documents\School_Work\Capstone\ChargeController\ChargeController_Main\ChargeController_Main.kicad_sch
Date: | 2/14/2024 12:39:02 PM
Tool: | Eeschema 7.0.8
Generator: | C:\Program Files\KiCad\7.0\bin\scripting\plugins/bom_csv_grouped_by_value.py
Component Count: | 56
Collated Components:
Item | Qty | Reference(s) | Value | LibPart | Footprint | Datasheet | DNP | Arrow Part Number | Arrow Price/Stock | Height | Manufacturer_Name | Manufacturer_Part_Number | Mouser Part Number | Mouser Price/Stock
1 | 3 | C1, C2, C3 | 10u | Device:C | ChargeController_Main_Library:CAPPRD250W65D630H900 | ~
2 | 1 | C4 | 4n | Device:C | Capacitor_THT:C_Disc_D14.5mm_W5.0mm_P7.50mm | ~
3 | 3 | C5, C16, C17 | 5u | Device:C | Capacitor_THT:C_Radial_D6.3mm_H7.0mm_P2.50mm | ~
4 | 1 | C6 | 50p | Device:C | Capacitor_SMD:C_1206_3216Metric | ~
5 | 2 | C7, C8 | 0.22u | Device:C | Capacitor_THT:C_Rect_L7.2mm_W2.5mm_P5.00mm_FKS2_FKP2_MKS2_MKP2 | ~
6 | 1 | C9 | 150u | Device:C | Capacitor_THT:CP_Radial_D6.3mm_P2.50mm | ~
7 | 1 | C10 | 22n | Device:C | Capacitor_SMD:C_1206_3216Metric_Pad1.33x1.80mm_HandSolder | ~
8 | 2 | C11, C12 | 0.1u | Device:C | Capacitor_SMD:C_1206_3216Metric_Pad1.33x1.80mm_HandSolder | ~
9 | 1 | C13 | 1n | Device:C | Capacitor_SMD:C_1206_3216Metric_Pad1.33x1.80mm_HandSolder | ~
10 | 1 | C14 | 10n | Device:C | Capacitor_SMD:C_1206_3216Metric_Pad1.33x1.80mm_HandSolder | ~
11 | 1 | C15 | 680p | Device:C | Capacitor_SMD:C_1206_3216Metric_Pad1.33x1.80mm_HandSolder | ~
12 | 1 | D1 | D_Schottky | Device:D_Schottky | ChargeController_Main_Library:SOD3716X145N | ~
13 | 1 | D2 | RFN10BM3STL | Main_Charge_Controller_Symbols:RFN10BM3STL | ChargeController_Main_Library:RD3P175SNFRATL | https://fscdn.rohm.com/en/products/databook/datasheet/discrete/diode/fast_recovery/rfn10bm3s-e.pdf |  |  |  |  | ROHM Semiconductor | RFN10BM3STL | 755-RFN10BM3STL | https://www.mouser.co.uk/ProductDetail/ROHM-Semiconductor/RFN10BM3STL?qs=yrxrYnY23DGBeQPMkvckXg%3D%3D
14 | 4 | H1, H2, H3, H4 | MountingHole | Mechanical:MountingHole | MountingHole:MountingHole_2.2mm_M2 | ~
15 | 1 | IC1 | ACS724LLCTR-05AU-T | Main_Charge_Controller_Symbols:ACS724LLCTR-05AU-T | ChargeController_Main_Library:SOIC127P600X175-8N | https://www.allegromicro.com/~/media/files/datasheets/acs724-datasheet.pdf |  | ACS724LLCTR-05AU-T | https://www.arrow.com/en/products/acs724llctr-05au-t/allegro-microsystems?region=nac | 1.75 | Allegro Microsystems | ACS724LLCTR-05AU-T | 250-724LLCTR05AUT | https://www.mouser.co.uk/ProductDetail/Allegro-MicroSystems/ACS724LLCTR-05AU-T?qs=pUKx8fyJudC3f6AQOezPDA%3D%3D
16 | 1 | IC2 | ABX00028 | Main_Charge_Controller_Symbols:ABX00028 | ChargeController_Main_Library:ABX00028
17 | 1 | IC3 | TLV9361QDCKRQ1 | Main_Charge_Controller_Symbols:TLV9361QDCKRQ1 | ChargeController_Main_Library:SOT65P210X110-5N | https://www.ti.com/lit/ds/symlink/tlv9361-q1.pdf?HQS=dis-mous-null-mousermode-dsf-pf-null-wwe&ts=1698578277040 |  |  |  | 1.1 | Texas Instruments | TLV9361QDCKRQ1 | 595-TLV9361QDCKRQ1 | https://www.mouser.co.uk/ProductDetail/Texas-Instruments/TLV9361QDCKRQ1?qs=ulEaXIWI0c9OtnSeYnzTIQ%3D%3D
18 | 1 | IC4 | LT3120JV#PBF | Main_Charge_Controller_Symbols:LT3120JV#PBF | ChargeController_Main_Library:QFN50P400X500X83-29N-D | https://www.mouser.jp/datasheet/2/609/lt3120-2401157.pdf |  | LT3120JV#PBF | https://www.arrow.com/en/products/lt3120jvpbf/analog-devices?region=nac | 0.83 | Analog Devices | LT3120JV#PBF | 584-LT3120JV#PBF | https://www.mouser.co.uk/ProductDetail/Analog-Devices/LT3120JVPBF?qs=QNEnbhJQKvYUJOxbUfIX7w%3D%3D
19 | 1 | J1 | SOLAR_PANEL | Connector:Screw_Terminal_01x02 | Connector_Wire:SolderWire-1sqmm_1x02_P5.4mm_D1.4mm_OD2.7mm | ~
20 | 1 | J3 | BAT_CHARGER1 | Connector:Screw_Terminal_01x06 | Connector_Wire:SolderWire-1sqmm_1x06_P5.4mm_D1.4mm_OD2.7mm | ~
21 | 1 | J4 | BAT_CHARGER2 | Connector:Screw_Terminal_01x06 | Connector_Wire:SolderWire-1sqmm_1x06_P5.4mm_D1.4mm_OD2.7mm | ~
22 | 1 | J5 | BAT1 | Connector:Screw_Terminal_01x02 | Connector_Wire:SolderWire-1sqmm_1x02_P5.4mm_D1.4mm_OD2.7mm | ~
23 | 1 | J6 | BAT2 | Connector:Screw_Terminal_01x02 | Connector_Wire:SolderWire-1sqmm_1x02_P5.4mm_D1.4mm_OD2.7mm | ~
24 | 1 | J7 | POWER_CONTROLLER | Connector:Screw_Terminal_01x02 | Connector_Wire:SolderWire-1sqmm_1x02_P5.4mm_D1.4mm_OD2.7mm | ~
25 | 2 | K1, K2 | G6RN-1-DC5 | Main_Charge_Controller_Symbols:G6RN-1-DC5 | ChargeController_Main_Library:G6RN1DC5 | https://datasheet.lcsc.com/szlcsc/Omron-Electronics-G6RN-1-DC5-BY-OMB_C231394.pdf |  |  |  | 15.5 | Omron Electronics | G6RN-1-DC5 | 653-G6RN-1-DC5 | https://www.mouser.co.uk/ProductDetail/Omron-Electronics/G6RN-1-DC5?qs=4BYd6zd2T8WY0IhOgkQoqg%3D%3D
26 | 2 | L1, L2 | 15u | Device:L | ChargeController_Main_Library:INDPM135125X500N | ~
27 | 1 | PS1 | TPS61170DRVR | Main_Charge_Controller_Symbols:TPS61170DRVR | ChargeController_Main_Library:SON65P200X200X80-7N | http://www.ti.com/lit/gpn/tps61170 |  | TPS61170DRVR | https://www.arrow.com/en/products/tps61170drvr/texas-instruments?region=nac | 0.8 | Texas Instruments | TPS61170DRVR | 595-TPS61170DRVR | https://www.mouser.co.uk/ProductDetail/Texas-Instruments/TPS61170DRVR?qs=pZC5fsuWujFeUvvbhM8Aeg%3D%3D
28 | 1 | Q1 | SI7272DP-T1-GE3 | Main_Charge_Controller_Symbols:SI7272DP-T1-GE3 | ChargeController_Main_Library:SI7288DPT1GE3 | https://www.vishay.com/docs/69026/si7272dp.pdf |  | SI7272DP-T1-GE3 | https://www.arrow.com/en/products/si7272dp-t1-ge3/vishay |  | Vishay | SI7272DP-T1-GE3 | 781-SI7272DP-GE3 | https://www.mouser.com/Search/Refine.aspx?Keyword=781-SI7272DP-GE3
29 | 6 | R1, R9, R13, R15, R17, R19 | 10k | Device:R | Resistor_THT:R_Axial_DIN0309_L9.0mm_D3.2mm_P5.08mm_Vertical | ~
30 | 1 | R2 | 14k | Device:R | Resistor_SMD:R_1206_3216Metric_Pad1.30x1.75mm_HandSolder | ~
31 | 1 | R5 | 2M | Device:R | Resistor_SMD:R_1206_3216Metric_Pad1.30x1.75mm_HandSolder | ~
32 | 1 | R6 | 100k | Device:R | Resistor_THT:R_Axial_DIN0309_L9.0mm_D3.2mm_P5.08mm_Vertical | ~
33 | 1 | R7 | 3.6k | Device:R | Resistor_THT:R_Axial_DIN0309_L9.0mm_D3.2mm_P5.08mm_Vertical | ~
34 | 1 | R8 | 30k | Device:R | Resistor_SMD:R_2512_6332Metric_Pad1.40x3.35mm_HandSolder | ~
35 | 1 | R10 | 620k | Device:R | Resistor_SMD:R_2512_6332Metric_Pad1.40x3.35mm_HandSolder | ~
36 | 1 | R11 | 76.8k | Device:R | Resistor_THT:R_Axial_DIN0309_L9.0mm_D3.2mm_P5.08mm_Vertical | ~
37 | 1 | R12 | 33k | Device:R | Resistor_THT:R_Axial_DIN0309_L9.0mm_D3.2mm_P5.08mm_Vertical | ~
38 | 1 | R14 | 140k | Device:R | Resistor_SMD:R_2512_6332Metric_Pad1.40x3.35mm_HandSolder | ~
39 | 1 | R16 | 17k | Device:R | Resistor_THT:R_Axial_DIN0309_L9.0mm_D3.2mm_P5.08mm_Vertical | ~
40 | 1 | R18 | 120k | Device:R | Resistor_SMD:R_1206_3216Metric_Pad1.30x1.75mm_HandSolder | ~

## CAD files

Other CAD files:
Documentation/Electrical/Schematics/Sources/ESP32_Schematic.dwg

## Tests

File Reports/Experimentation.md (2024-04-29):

# System Measures of Success

These measures of success are derived from the project proposal.

| Measure of Success | Name | Details |
|---|---|---|
| M1 | Full Time Operation | All parts of the system shall be constantly functioning. This includes having a backup power supply. |
| M2 | Wireless Communication | The sensor shall communicate with the server wirelessly.|
| M3 | Local Space Availability Retention| The sensor shall keep track of the amount of vehicles in a parking lot locally.|
| M4 | Space Availability Retention | The system shall keep a local count of vehicles that enter or exit a parking lot.|
# System Constraints
| Constraint Number | Constraint Information | Subsystem Defined | 
|---|---|---|
| C1  | Subsystem shall detect cars/pickup trucks (vehicles) that are entering and exiting a parking lot. | Loop Controller |
| C2  | Vehicle detector shall be compliant with the FCC frequency range for Intentional Radiators and verifying the detector is within permissible part 15 frequencies.  | Loop Controller |
| C3  | Each entrance/exit of a parking lot shall use a total of one loop controller that will control the two inductive loops at the entrance/exit. | Loop Controller |
| C4  | The Loop Controller shall be connected to the ESP32 Microcontroller that is used with the Data system of the project to communicate a change in frequency in both of the loops and determine whether a vehicle is entering or exiting a parking lot. | Loop Controller |
| C5  | Data shall be transmitted on the unlicensed 915 MHz ISM band bounded by 902 MHz and 928 MHz. | Data Subsystem |
| C6  | Data shall be transmitted according to the standards set by The LoRa Alliance that define the LoRa protocol.| Data Subsystem |
| C7  | The system shall be able to communicate effectively over a distance of 915 meters or 1 kilometer in order to scale over all of campus. This is the approximate distance from Brown Hall to the far edge of Purple Lot. This was determined to be the farthest point on campus from Brown Hall using Google Maps. This distance must be achieved even when the signal has to pass through several layers of material.| Data Subsystem |
| C8  | The system is constrained by the limited data rate that is inherent to the LoRaWAN protocol. Specifically, the bit rate can range between 0.3 kbps to 27 kbps depending on the spreading factor and bandwidth used.| Data Subsystem |
| C9  | The system is constrained by the maximum payload size afforded by LoRaWAN. Depending on the spreading factor, the maximum payload size can range from 51 bytes to 222 bytes.| Data Subsystem |
| C10 | Subsystem shall detect cars/pickup trucks (vehicles) and motorcycles that are entering a parking lot at a maximum speed of 20 mph and leaving a parking lot at a maximum speed of 20 mph. | Ground Based Sensor Subsystem|
| C11 | Vehicle detector shall cover a range of at least 50 &mu;H to 1000 &mu;H at a frequency at 50 kHz | Ground Based Sensor Subsystem |
| C12 | Vehicle detector shall be compliant with the FCC frequency range for Intentional Radiators and verifying the detector is within permissible part 15 frequencies.| Ground Based Sensor Subsystem |
| C13 | Each entrance/exit of a parking lot shall have a total of two inductive loops for determining whether a car/pickup truck is entering a parking lot or leaving a parking lot.| Ground Based Sensor Subsystem |
| C14 | All components of the subsystem, with the exception of the inductive loops and lead-in wire to the induction loops, shall be placed in an area that does not affect pedestrian traffic along the road or nearby sidewalks.| Ground Based Sensor Subsystem |
| C15 | All turns in the inductive loop shall be a 45° turn (or 135° as noted in the schematic drawing) to avoid damaging the wire(s) that create the inductive loop that comes from using 90° turns. | Ground Based Sensor Subsystem |
| C16 | Any wire that is used as part of the loop and is connected to the vehicle detector shall be protected using a heavy-duty cable protector that is capable of protecting the wires under the weight of a vehicle or pedestrian while protecting the wires from the weather. | Ground Based Sensor Subsystem|
| C17 | Vehicle detector shall detect vehicles and motorcycles that are tailgating (when the front bumper of one vehicle is close to the back bumper and the two vehicles are in the same loop at the same time on one side of the roadway).| Ground Based Sensor Subsystem |
| C18 | Vehicle detector shall detect vehicles and motorcycles that are going in opposite directions on the roadway, but are within the detection range of the same loop at the exact same time.| Ground Based Sensor Subsystem |
| C19 | Inductive loops shall be placed a minimum of 4 ft. apart from the edge of one loop to the edge of the other loop to avoid cross talk between the loops and possibly give false signals.| Ground Based Sensor Subsystem |
| C20 | Voltage equivalence: The main wall power subsystem needs to protect devices from the damage caused by voltage and guarantee the safety of the electrical system, as well as preserve the whole subsystem. | Wall power Subsystem |
| C21 | During main power failures, power flow is controlled by the switch controller. | Wall power Subsystem |
| C22 | It should be within wire capabilities. | Wall power Subsystem |
| C23 | Must be a kill switch to disconnect all the power from the source. | Wall power Subsystem |
| C24 | The subsystem shall power each subsystem's demanded voltage and current with a 10% tolerance. | Power Controller Subsystem |
| C25 | The subsystem output shall be connected to the other subsystems through three fuses.| Power Controller Subsystem |
| C26 | The subsystem shall have a DC nominal voltage of 12V. | Power Controller Subsystem |
| C27 | Controller shall maximize the output power from the solar panel. | Charge Controller Subsystem |
| C28 | Controller shall output 12 V with a 10% tolerance to the Power Controller. |Charge Controller Subsystem |
| C29 | Controller shall prevent the batteries from being damaged due to over-charging | Charge Controller Subsystem |
| C30 | The solar panel and the backup battery shall be connected to the charge controller. | Solar Power Subsystem |
| C31 | The solar panel should be installed at the right direction and angle that can capture the maximum amount of sunlight. | Solar Power Subsystem |
| C32 | The charge controller shall maximize the output power from the solar panel. | Solar Power Subsystem |
| C33 | The backup battery shall have enough capacity to prevent the charge controller from discharging more than 50%. | Solar Power Subsystem |
| C34 | The backup battery shall either be in the charging or discharging phase, and it cannot be in both simultaneously. | Solar Power Subsystem |

## Loop Controller Subsystem and Ground Based Sensor Subsystem Experimentation

### Design Changes

   For the Loop Controller, the original idea of the team was to use a Diablo DSP-21 Vehicle Detector to control the inductive loops and send a signal to the ESP32 MCU alerting of when a vehicle
enters or exits a parking lot.  However, it was decided that it would be more feasible to build a Loop Controller instead of purchasing the Diablo DSP-21 Vehicle Detector.  After numerous designs
and discussions as a team, it was decided that it would best to use a Colpitts Oscillator circuit to generate a frequency through the inductive loops as the Colpitts oscillator provides the most
stable frequency compared to circuits such as a Hartley oscillator, etc.  In order to allow the ESP32 to monitor the frequency of the inductive loops safely, a Sine to Square Wave circuit was
connected to the output of the Colpitts oscillator.  A voltage regulator was added to the Loop Controller to transform 9 V to 3.3 V so the output of the Sine to Square Wave circuit would send the square wave to the ESP32 at the safe voltage of 3.3 V to the GPIO pins.  By creating a Custom Loop Controller, the Loop Controller is designed with the needs of the project in mind and we have a more in-depth understanding of the Loop Controller in the event of troubleshooting any possible issues that may occur in the controller.

For many of the constraints of the Ground Based Sensor Subsystem, they were either revised or descoped based on the decision of designing the Loop Controller in-house instead of purchasing the Diablo DSP-21.  Each constraint for the Ground Based Sensor Subsystem and the Loop Controller Subsystem is explained in the following section.	

### Loop Controller Constraints

### C1
Subsystem shall detect cars/pickup trucks (vehicles) that are entering and exiting a parking lot.

   - This constraint was achieved as proven in the results.
   
### C2 and C12
Vehicle detector shall be compliant with the FCC frequency range for Intentional Radiators and verifying the detector is within permissible part 15 frequencies.

   - This constraint was achieved as proven in the results.
   
### C3 and C13
Each entrance/exit of a parking lot shall use a total of one loop controller that will control the two inductive loops at the entrance/exit.

   - This constraint was achieved as the Loop Controller that was used for Experimentation controls both inductive loops accordingly and the frequency of both inductive loops are similar to the expected results in the Loop Controller Signoff.
   
### C4
The Loop Controller shall be connected to the ESP32 Microcontroller that is used with the Data system of the project to communicate a change in frequency in both of the loops and determine whether a vehicle is entering or exiting a parking lot.

   - This constraint was achieved and further evaluation of this constraint is located in the experimentation of the ESP32 frequency vs time measurement section below.

### C10
Subsystem shall detect cars/pickup trucks (vehicles) and motorcycles that are entering a parking lot at a maximum speed of 20 mph and leaving a parking lot at a maximum speed of 20 mph.

   - This constraint was not fully achieved as motorcyles were never tested throughout the experimentation phase of the project.  However, cars/pickup trucks were detected as stated in C1.

### C11 
Vehicle detector shall cover a range of at least 50 μH to 1000 μH at a frequency at 50 kHz

   - This constraint is descoped due to the previously mentioned design changes.

### C14
All components of the subsystem, with the exception of the inductive loops and lead-in wire to the induction loops, shall be placed in an area that does not affect pedestrian traffic along the road or nearby sidewalks.

   - This constraint was achieved as the equipment was placed away from pedestrian traffic and pedestrians were able to walk on the sidewalks without being affected by the placement of the Loop Controller.  For the lead-in wire connections to the inductive loops, measurements were taken from the center of the roadway to the edge of the concrete to determine the minimum distance to avoid interfering with pedestrian traffic.  With the minimum distance determined, extra length was added to the lead-in connnections to avoid possible human errors when calculating the distance.

### C15
All turns in the inductive loop shall be a 45° turn (or 135° as noted in the schematic drawing) to avoid damaging the wire(s) that create the inductive loop that comes from using 90° turns.

   - This constraint was achieved as all turns in each inductive loop were set as close as possible to a 45° angle.

### C16 
Any wire that is used as part of the loop and is connected to the vehicle detector shall be protected using a heavy-duty cable protector that is capable of protecting the wires under the weight of a vehicle or pedestrian while protecting the wires from the weather.

   - This constraint is descoped due to the previously mentioned design changes.

### C17
Vehicle detector shall detect vehicles and motorcycles that are tailgating (when the front bumper of one vehicle is close to the back bumper and the two vehicles are in the same loop at the same time on one side of the roadway).

   - This constraint was not achieved due to time constraints and requires further evaluation of both the Loop Controller and Data Subsystem in order to meet this constraint.

### C18 
Vehicle detector shall detect vehicles and motorcycles that are going in opposite directions on the roadway, but are within the detection range of the same loop at the exact same time.

   - This constraint was not achieved due to time constraints and requires further evaluation of both the Loop Controller and Data Subsystem in order to meet this constraint.

### C19 
Inductive loops shall be placed a minimum of 4 ft. apart from the edge of one loop to the edge of the other loop to avoid cross-talk between the loops and possibly give false signals.

   - This constraint was achieved as all inductive loops were placed at a distance greater than 4 ft apart from each loop.  The distance allowed the loops to avoid cross-talk between one another and all signals received from the loops were similar to the expected results.

### Oscilloscope Testing - Purpose of the Experiment

The purpose of this experiment is test the Loop Controller and 
its function and verify it operates as it is intended.  

### Oscilloscope Testing - Experimental Procedure

For all tests, the loop(s) were placed in the road and the 
vehicle passed over the loop(s) and not to the side of the loop(s).  Throughout 
the entirety of the tests, it is expected that the frequency of the 
loops/Loop Controller will change with a noticeable difference of ± 1 
kHz and this change will be detected by the ESP32 MCU to send 
information to the server alerting of the mentioned sedan 
entering/exiting a parking lot.  To monitor the changes in frequency in both inductive loops,
the results for each test are found when using a Rigol DS1104 Oscilloscope.

### Oscilloscope Testing - Results

#### No Loop(s) Connected to the Controller
| | Expected Results | Actual Results |
|---|---|---|
| Input  | 9 VDC | 9.19 VDC |
| Output | 3.3 VDC | 3.3 VDC |

#### One Loop Connected to Controller with No Speed Test
| | Set Frequency | Max. Frequency |
|---|---|---|
| Test 1 | 62.9 kHz | 66 kHz |
| Test 2 | 62.9 kHz | 67 kHz |

#### Two Loops Connected to Controller
### 5 mph
| | Set Frequency | Max. Frequency |
|---|---|---|
| Loop A | 62.9 kHz | 65 kHz |
| Loop B | 62.9 kHz | 69 kHz |

### 10 mph
| | Set Frequency | Max. Frequency |
|---|---|---|
| Loop A | 62.9 kHz | 64.5 kHz |
| Loop B | 62.9 kHz | 64.5 kHz |

### 15 mph
| | Set Frequency | Max. Frequency |
|---|---|---|
| Loop A | 62.9 kHz | 64.1 kHz |
| Loop B | 62.9 kHz | 66.7 kHz |

### 20 mph
| | Set Frequency | Max. Frequency |
|---|---|---|
| Loop A | 62.9 kHz | 64.9 kHz |
| Loop B | 62.9 kHz | 63.3 kHz |

### Oscilloscope Testing - Interpretation

For the first two trials, one loop was connected to the Loop Controller (Loop A Output).  When one loop was connected, there was no set speed value (in mph) and the Loop Controller detected when a vehicle passed over the loop.  Two trials were completed to verify the Loop Controller did function as expected and was not by coincidence.  In both Test 1 and Test 2 (as seen in the graph), the frequency of the loop increased by more than 3 kHz every time.  From this data, we can interpret that the Loop Controller does function as expected and can detect a change in frequency due to a vehicle passing over the loop.

For trials 3-7, both loops were connected to the Loop Controller (Loop A Output and Loop B Output).  The speed of the vehicle was included and increased at increments of 5 mph until it reached a maximum speed of 20 mph for a total number of four tests/trials.  For speed values of 5, 10, and 15 mph, the frequency in both loops experienced a change of +1 kHz.  This change in frequency is expected as the ESP32 MCU will be able to detect the 1 kHz change in frequency and update the delta accordingly.  For the speed value of 20 mph, Loop B Output experienced a change of less than 1 kHz (change in frequency is 400 Hz). Depending on the ESP32's algorithm for detecting changes in frequency, this may not be considered a significant enough change to count as a vehicle.

Based on the test results above, the Loop Controller is able to detect vehicles passing over the loop(s) that are entering or exiting a parking lot based on the information that is received in the data tables.

### ESP32 Testing - Purpose of Experiment
The purpose of this experiment is to test that the ESP32 can read the square wave pulses from the Loop Controller PCB and determine if a vehicle is entering or exiting a parking lot (Constraint 4).

### ESP32 Testing - Experimental Procedure
The Loop Controller PCB outputs are connected to two GPIO pins on the ESP32 microcontroller. The ESP32 outputs what frequency it is reading, changes in delta, and a timestamp to the serial terminal. This output is logged and put into a CSV file so the data can be graphed. Data will be logged as vehicles drive over the loops.

### ESP32 Testing - Results
#### Frequency vs Time with Vehicle Traveling at 5 mph


#### Frequency vs Time with Vehicle Traveling at 15 mph


#### Frequency vs Time with Vehicle Traveling at 20 mph


#### Frequency vs Time with Vehicle Traveling at Random Speeds
Freq_vs_time_random_zoomed
The large dip in the graph can be attributed to connection problems with the wires.

### ESP32 Testing - Interpretation
These graphs show that the ESP32 is capable of reading the square waves generated by the Loop Controller and effectively calculate the frequency of the square wave pulses. This video demonstrates the ESP32's ability to determine the direction a vehicle is traveling and update the delta accordingly. Link to video: https://youtube.com/shorts/8B8lnqCkGT8?si=NU7qAhg_zqjL0T57 

This proves constraint 4 is met. C4: "The Loop Controller shall be connected to the ESP32 Microcontroller that is used with the Data system of the project to communicate a change in frequency in both of the loops and determine whether a vehicle is entering or exiting a parking lot."

## Wall power Subsystem Experimentation

| Constraint Number | Constraint Information |
|--|---|
| C20 | Voltage equivalence: The main wall power subsystem needs to protect devices from the damage caused by voltage and guarantee the safety of the electrical system, as well as preserve the whole subsystem. | Wall power Subsystem |
| C21 | During main power failures, power flow is controlled by the switch controller. | Wall power Subsystem |
| C22 | It should be within wire capabilities. | Wall power Subsystem |
| C23 | Must be a kill switch to disconnect all the power from the source. | Wall power Subsystem |

### C20
The subsystem has fuses that protect all the connected subsystems from damage caused by voltage. There is also a fuse between the outlet power and the backup battery to ensure the electrical system is safe.
This constraint has been achieved. 
### C21 and M1
When the outlet power is disconnected, the controller switches to use the main battery after a delay of less than a second. During this delay, the output voltage is zero.

This constraint has been achieved, but M1 has not been achieved as there is a small delay where the output voltage is zero and the system is shut down.
### C22
This constraint was successful. Normal jumper wires can handle the voltage and amperage sent to each subsystem.

### C23
This constraint was successful. A physical kill switch has been connected to shut down all the power if required.

### Purpose of the Experiment
This experiment will be testing the error of the voltage regulators and the switching functionality.

### Experimental Procedure

The PCB’s input has been connected to both a wall outlet through an adapter and a backup battery. The Loop Controller PCB and the Data Subsystem has been connected to the outputs to test the power output of this subsystem’s PCB. Fuses have been used in between the outputs and the external PCBs.

### Prediction
The Loop controller should be receiving 9 VDC, 0.05 A and Data subsystem should be receiving  5.5 VDC and 0.25 A.    
### Results

| Trial No.  | Data Subsystem Voltage & Current | Loop Controller Voltage & Current  |
|---|---|---|
|1	 | 5.4186 VDC & 0.219597 A  |	9.3034 VDC & 0.052276  A |
|2		| 5.4226 VDC & 0.219818 A  |	9.3035 VDC & 0.052314  A |
|3		| 5.4145 VDC & 0.219518 A  |	9.3040 VDC & 0.052397  A |

The above table shows the output of the PCB with a wall outlet through a wall adapter on the input. 



The graph above shows the power consumed by the Data Subsystem with the wall outlet input.



The graph above shows the power consumed by the Loop Controller PCB with the wall outlet input.

| Trial No.  | Data Subsystem Voltage & Current | Loop Controller Voltage & Current |
|---|---|---|
|1 	| 5.4143  VDC & 0.219523 mA | 	9.1858 VDC  &  0.052397 mA |
|2		| 5.4226  VDC & 0.219814 mA |	 9.1865 VDC  &  0.052438 mA |
|3		| 5.4187  VDC & 0.219632 mA |	 9.1863 VDC  &  0.052419 mA |

The above table shows the output of the PCB with the backup battery suppling the input. 



The graph above shows the power consumed by the Data Subsystem with the battery input.



The graph above shows the power consumed by the Loop Controller PCB with the battery input.

Measurements of the voltage and current are given in the video link below. For both, the power sources are input 12 VDC.

https://www.youtube.com/watch?v=EA21rRr-S3c 

### Experimental Interpretations

The output’s power tolerance with the wall outlet input can be shown below:

| No.| Subsystem | Expected Voltage | Actual Voltage |  Expected Current | Actual Current |Power Tolerance | 
| ---  | --- | ---|---|---|---|---|
| a  | Sensor | 9  VDC  | 9.303 VDC  | 0.05 A  | 0.0523 A |  8.12 %  | 
| b  | Data Subsystem | 5.5 VDC  | 5.48 VDC  | 0.25 A  | 0.2194 A  | 15.4 %  | 

The output’s power tolerance with the backup battery input can be shown below:

|No. | Subsystem | Expected Voltage | Actual Voltage| Expected Current | Actual Current |Tolerance |
|--- |---|---| ---|---|---|---|
| a  | Sensor | 9  VDC | 9.303 VDC | 0.05 A  | 0.0524 A | 7.91 %  | 
| b  | Data Subsystem | 5.5 VDC | 5.418 VDC | 0.25 A| 0.2196 A | 13.04  % | 

While not all power outputs are within the 10% tolerance, each subsystem safely receives an ample amount of power to function properly.

## Power Controller Subsystem Experimentation

| Constraint Number | Constraint Information |
|--|---|
| C24 | The subsystem shall power each subsystem's demanded voltage and current with a 10% tolerance|
| C25 | The subsystem output shall be connected to the other subsystems through three fuses|
| C26 | The subsystem shall have a DC nominal voltage of 12V |

### Purpose of the Experiment
To test the error of the voltage regulators.
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

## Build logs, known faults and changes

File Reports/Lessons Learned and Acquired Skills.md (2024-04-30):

# Abdulrahman Alrudayan
## What went well? 
At the beginning of the Capstone one, we chose to have weekly meetings with our supervisor as a team. Every two weeks, we meet with our sponsors. However, at each meeting, we have a target to do something. Also, at every meeting, we made decisions about new details for each one. Also, if we face some problems, we can fix them early together as a group. We kept up these weekly meetings throughout capstone two, which kept us very successful. Even during Christmas break, we met once every week in teams. We worked on our problem and what’s the new update. That is shown as necessary to help us reach our goals.

Furthermore, the wall power subsystem was carefully designed, soldered, and selected components in specific sizes and chips, such as adapter power supply, chips “buck converters,” inductors, capacitors, resistors, relay switches, and backup batteries. The main thing for my subsystem is to step down the voltage and current to feed each of the two subsystems. Both components were carefully calculated to provide reliable results.

## What did not go well? 
Everything goes well. In capstone one, I struggled to understand how to select some components such as, chips  and switches. 

## What “best practices” have you identified? 
I really understood how to select the components and design PCBs with soldered components, especially chips. For the chips “buck converter,” do not use the Weller soldering station. You can use surface mount ICs, which are excellent.

## What unanticipated problems occurred? 
It was hard to find a thin resistor, and I could not find much with a higher than ¼ power rating. So, I choose the thick film resistor. However, it allows me to solder by surface. Also, in PCB, “ 2512” is used for the thick film resistor.

## What would you do differently if you were able to do it over again? 
 If I was able to do it again. I will choose a thin film resistor.
## What new knowledge or skills did you acquire throughout Capstone? 
I learned many things, such as Kicad, designing PCB, buck converter "step down," and the switch can be a controller between the wall power and backup battery, and this controller manages the voltage between them.

# Khalifah Altamimi
## What went well? 
Our group's decision to hold weekly meetings proved instrumental in accomplishing our goals and resolving design phase challenges.The significant impact of these sessions was great.Each meeting was goal-oriented, ensuring efficient use of time and focused discussions.

Through consistent communication, we addressed issues promptly, brainstormed solutions, and maintained a sense of unity. This commitment to regular meetings exemplified the power of structured communication in driving success in group endeavors.

The Power Controller subsystem was meticulously designed and soldered to efficiently step down voltage and supply the necessary currents to all project subsystems. Moreover, it incorporated safety measures by utilizing fuses to ensure a secure power path.

Meanwhile, the Solar Power subsystem was meticulously designed and implemented. The solar panel successfully provided the required voltage to the charge controller, while the backup battery ensured uninterrupted power supply. Both components were meticulously calculated to meet the system's voltage and current requirements, ensuring reliable operation.

## What did not go well? 
A problem occurred with the Power Controller subsystem when one of its outputs had a tolerance higher than 10%. 

## What “best practices” have you identified? 

I have learned that designing a PCB requires careful attention because even a small issue could cause a short circuit. Another important practice is to print the PCB and check the component sizes and layout for accuracy.

## What unanticipated problems occurred? 

The only unanticipated problem I faced was selecting a very small SMD size for all resistors on my PCB. 

## What would you do differently if you were able to do it over again? 

I would print the PCB design on paper, and then I would be able to see the actual size of all the components on my PCB. If an issue were found, I could change the size or redesign the PCB to get the best outcome. 

## What new knowledge or skills did you acquire throughout Capstone? 

I learned many new things, such as designing PV systems, voltage regulators, and PCBs. These new skills helped me determine what I prefer to do in the future. Moreover, each skill and knowledge I acquired was the key to accomplishing my assigned subsystem. 

# Brady Beecham
## What went well? 

We chose to have weekly meetings for just the team, weekly meetings with our supervisor, and biweekly meetings with our sponsers. Continuing to have these weekly meetings even into capstone two played a huge part into our success.

Another thing that helped our team succeed is our willingness to work over christmas break. We met once a week over break and it saved us weeks as we were able to problem solve in a much more relaxed environment (i.e. not having four other classes to worry about.)

## What did not go well? 

For our team, everything went very smooth due to how often we met during the project. Any problem that came up for an individual was able to be solved as a team. 

For my design specifically, populating and testing my pcbs did not go well. While the design should work if soldered properly, the chips chosen (QFN chips) were not novice friendly and crippled my subsystem.

## What “best practices” have you identified? 

### Communication is key
Meet once a week with just the team and another time with your supervisor (especially capstone one!!!) The team meeting can just be updates and keeping track of any problems that come up. It is surprisingly helpful explaining your problems to others who understand (helpful with problem solving and also mentally. It's a long project, lean on your teammates and let your teammates lean on you.) The supervisor meeting should be a simple check in and to get validation that what you are designing aligns with the problem / what is being asked. 

### Design PCBs with the soldering in mind
If possible, always use IC chips that have leads. Do not use no leads ICs. Surface mount ICs are pretty simple to solder with the right equipment. ( Use Conard's equipment! It's great!)

### Know about the electrical engineer on campus. He's great
Talk to Conard (the electrical engineer on campus) for any PCB questions or advice in general. He is here to help.

### Comminucation is key

This is so important I'm putting two sections about it!!!

Talk about the problems you are facing with your teammates, even if you feel stupid for not knowing how to solve it at that moment. It will save you time and help your teammates gain confidence about sharing problems they are facing as well. It is much better knowing about problems everybody is facing BEFORE meeting with your supervisor. 

## What unanticipated problems occurred? 

Some problems came up after not talking to our supervisor properly. We had to scrap some subsystems and come up with new subsytem ideas near the end of capstone one. This was as frustrating as you imagine. With better communication with our supervisor earlier in capstone one, this problem would not have occured. 

Another problem arose due to not being adament about _everybody_ having to share how their design was going during capstone one. Some simple problems/misunderstandings came up that could have been easily fixed if designer was more open about the problems they were facing. 

## What would you do differently if you were able to do it over again? 

I would replace all QFN ICs with ICs that have leads.

I would also split up my main pcb into at least two pcbs so that once a single circuit is proven, that pcb can be set aside. (I had a circuit that broke after being proven due to having to put the whole pcb back into the heat oven for a different circuit.) Note that this would have caused a more complex wiring once the pcbs were complete, but I think it's worth it.

Each PCB should have only one function. (Very similar to how each function in code should only have one job.) 

## What new knowledge or skills did you acquire throughout Capstone? 

I learned about PCB design and also really understood circuit design for the first time.

While I did well in all of the circuits and electronics classes, I never really _got it_ with circuit design. Since I'm a computer engineer and not a electrical engineer it was easy to tell myself that not having a great feel for circuit design is acceptable. It is not. Getting a good feel for circuit design is the most valuable hard skill / lesson I got from capstone.

Communicating engineering problems is the best soft skill that I learned. Having so many meetings made this skill nearly impossible not to learn.

# Kyle Plant
## What went well? 
1. The utilization of the Pulse Counter hardware module of the ESP32 microcontroller. The PCNT module of the ESP32 allows for the measurement of frequencies up to 40 MHz supposedly (I have not tested that myself), so we had plenty of resolution for measuring the frequencies of the loop controller, which range from 50-75 kHz. The sampling window just needs to be adjusted to match the frequency you are trying to measure. If you have too long of a sample period and a high-frequency signal, the PCNT module can overflow and get set back to 0 in that amount of time. Each PCNT unit uses a 16-bit signed counter register and 2 channels that can either increment or decrement the count on the register. So, that means a maximum of 32767 and a minimum of -32768.
2. LoRaWAN with The Things Stack, eventually. Once I found a good library that works how I need it to, allowing me to split up the LoRaWAN functionality into tasks under FreeRTOS, getting set up with The Things Stack was easy. I used this library https://github.com/manuelbl/ttn-esp32 with the ESP-IDF. With this library, I was able to use Over-the-air authentication (OTAA) to connect to the gateway and send and receive messages with range in excess of 1 km. Setting up the gateway was also easy. I just had to download the sx1302 hardware abstraction layer and make some changes in the global config file for it to register with my TTS application. Also, the WM1302 has u.FL connectors RFIO and ANT. The RFIO connection is on the mini PCIE PCB and the ANT is on the PiHat. The one labeled ANT IS NOT WHERE YOU PLUG IN THE ANTENNA! You plug the antenna for your gateway into the RFIO connection and ANT is for something like a GPS module. Connecting my antenna correctly increased my range from 60m  to over 1 km.
3. The static threshold over rolling average algorithm I used for vehicle detection and directional logic in the ESP32 code. The algorithm used for directional logic as I call it is very simple but effective. Over 160 tests we got 96% accuracy. It works by comparing new frequency samples to the rolling average frequency per loop. The rolling average is calculated by taking the average of an array containing the most recent measured frequencies. The array size can be changed to make it more or less reactive to change. We compare the new frequencies to that average and see if they exceed the average by the specified threshold value. If the new frequency exceeds the threshold we push a loop event to a queue containing the loop ID, frequency, and timestamp. We read from that queue using a different task. That task is the directional logic proper. It looks for consecutive events with different loop IDs and also checks if the delta change is in "timeout" or if the event is deemed unrelated or "stale." Timeout is an easy way of debouncing. It is simply a time after the delta is changed that has to pass before the delta can be changed again. Staleness determines if the two events are close enough in time to be related to each other. Based on the conclusions, the delta will be updated based on the order of loop IDs in the queue.
4. ESP-IDF. The ESP-IDF gives much better control of the ESP32 hardware. It is built with FreeRTOS in mind and I highly recommend the ESP-IDF be used over Arduino for more complex applications.

## What did not go well?  
1. LoRaWAN with ChirpStack. Setting up the Raspberry Pi to work with ChirpStack as its individual components and also running the Gateway OS was much more complicated than The Things Stack. I highly recommend TTS over ChirpStack if you want something straightforward.
2. Finding good LoRaWAN libraries for Arduino/ESP-IDF that work well with FreeRTOS. I recommend the ESP-IDF if you need more control over your LoRaWAN code.
3. Speed estimation. This was tried out in the ESP32 code. We wanted to be able to determine the speed a vehicle travels over the loops, but I could not find a good way to implement it due to the fixed sample period of the Pulse Counter task. That resulted in wildly inaccurate speeds.
4. ESP32 with RFM95W LoRa radio transceiver still takes absolutely forever to join TTS network sometimes.

## What “best practices” have you identified? 
1.	"Being a good neighbor" with The Things Stack. To be a good neighbor with your LoRaWAN network under The Things Stack/The Things Network, you should transmit infrequently and not have excessive range. Transmitting all the time and having enormous range makes you a "noisy neighbor" because they will pick up all your transmissions, possibly causing them to miss some of their own messages.
2.	Feeding the watchdog with ESP32 and FreeRTOS in ESP-IDF. You should subscribe tasks to the task watchdog and reset it at regular intervals while avoiding any form of blocking code or else you will trigger the watchdog. You do not want your device to enter a state where it will have to reset because the watchdog was not fed.

## What unanticipated problems occurred? 
1. LoRaWAN range was much lower than expected initially, but this was later solved by connecting the antenna to the correct connector on the WM1302. ANT is not where you put the antenna, RFIO is...

## What would you do differently if you were able to do it over again? 
1. Not spend so much time trying to get LoRa physical layer or LoRaWAN with ChirpStack to work and instead just start with LoRaWAN with The Things Stack.
2. Develop a more sophisticated algorithm that can classify the vehicles it detects. For example, if it is a car or a truck.
3. Test motorcycles because everyone always asks about them.

## What new knowledge or skills did you acquire throughout Capstone? 
1. LoRa and LoRaWAN as a whole.
2. The Things Stack.
3. ChirpStack.
4. ESP32 hardware.
5. ESP-IDF.
6. FreeRTOS.
7. Better teamwork skills.

# Michael Sisk

## What did not go well?  

1. At the beginning of Capstone 1, the team inherited a continuation project and struggled to understand the necessary direction of the project and whether to continue building with cameras or research for other methods of monitoring parking lots.  The first two technical reports were not as great as they could have been when looking at Capstone 1.  After the first report, the team completed more in-depth research on how inductive loops truly worked, how to utilize them in the project, how the idea would be more suitable for Tech’s campus versus cameras, and how to explain and defend the idea in the Conceptual Design. 

## What did go well? 

1. After understanding the direction of the project, the team was able to work effectively together with the common goal of building a proof of concept system that uses inductive loops to monitor parking lots and that they are a more suitable option over cameras. 

2. Once the team direction of the Loop Controller changed from understanding how someone else built their controller and trying to create similar designs to using an oscillator and sine to square wave circuit, the Loop Controller became simple in both simulation results and experimentation results.  At the end of experimentation, the Loop Controller was able to detect vehicle movement over the inductive loops due to a change in frequency from the inductive loops. 

## What “best practices” have you identified? 

1. For the Loop Controller, the team assumed we would need two PCBs as the Engineering Quad has two entrances/exits.  In the ordering parts stage of the Loop Controller, the correct number of parts needed for two PCBs was ordered and though the team later decided to use one PCB instead of two, the parts that were for the second PCB became spares.  This proved useful as some of the components on the first PCB had issues and needed to be replaced.  By having the extra components, the Loop Controller issues were resolved and testing could continue on the Loop Controller. 

2. When starting in Detail Design, having a central location to place all documentation makes the designs simpler as when you need help on a design, the team can easily access the documentation you have and better resolve the issue at hand without having to wait on you to send all the information via email.  This was very useful when the Loop Controller was still being completed over the Winter Break as every teammate was able to see the work done and what was still unfinished.  The team was also able to complete more in-depth research of both the Loop Controller and other subsystems that were being designed during the Winter Break. 

## What unanticipated problems occurred? 

1. For the Loop Controller, the Linear Voltage Regulator pinout was incorrect. The datasheet for the component was reversed and this caused major issues as it would send 8.5 VDC to the Comparator (maximum voltage for the comparator is 7.5 V).  For the Comparator, it did not have an indented notch as most IC chips normally have to specify the top side of the component.  Due to this, the first Comparator was placed on the PCB incorrectly and with the issue of higher than maximum voltage being sent to the incorrect pin of the Comparator, the Comparator was replaced with a new component.  Since the team unanimously agreed to order extra of every component for all designs, both the Linear Voltage Regulator and the Comparator were replaced in the same day and there was no downtime due to the incorrect datasheets and the missing indented notch for the Comparator. 

## What would you do differently if you were able to do it over again? 

1. For the Loop Controller, the original plan was to find a DIY Loop Controller someone had previously built and understand how it works through the design.  This proved to be not useful as it was impossible to simulate the design and produce the same results.  For all circuits that are DIY, find the basic level circuits necessary to complete the objective and combine the circuits together one at a time and constantly test to verify the circuits work together accordingly.  This process will save lots of time and avoid numerous headaches that would come with trying to understand someone else’s work. 

## What words of wisdom would you pass on to future students? 

1. Continue having meetings through Capstone 2 

    a. Thanks to having a team meeting once every week (sometimes twice depending on deadlines), meeting with NAVSEA every other week, and constant communication through Discord, everyone was able to stay informed of what was happening for all subsystems.  For issues that occurred, the team was able to stay well informed of the issue and how to resolve issues before it was too late to do anything about it. 

2. Utilize every team member’s strengths to help the team 

    a. By learning what every team member’s strengths for subsystem development, technical writing, etc., each team member was able to contribute significantly to the project.  By utilizing each team member’s strengths, everyone in the project will be able to utilize the knowledge they have obtained over their undergraduate studies and apply it to the project. 

3. The original ideas of how the project will be at the end of Capstone will more than likely change throughout the project. 

    a. At the beginning of Capstone, the original idea was to measure inductance and voltage change of the inductive loops.  This was not the case as it was simpler to monitor change in frequency and to also use a custom-built controller that was designed in house and not use a prefabricated controller to monitor the inductive loops.  The original idea of the inductive loops and the loop controller changed over the course of the project and was simpler to use the final product than to use the ideas generated at the beginning of Capstone. 

## What new knowledge or skills did you acquire throughout Capstone? 

1. During the course of this project, I learned how to draw schematics and create PCB layouts using KiCAD software.  Through numerous drawings for both the Loop Controller and Ground Based Sensors, I was able to create schematics and PCB layouts that were simple to follow and understand as to how each component was connected to other components. 

2. For technical documentation, I obtained a better understanding of IEEE format using LaTeX in Overleaf and how to write effective technical documentation for projects. 

3. Besides the technical knowledge acquired in Capstone, I learned more on how to work with a team and how to communicate effectively so everyone on the team has the same understanding of the discussion.

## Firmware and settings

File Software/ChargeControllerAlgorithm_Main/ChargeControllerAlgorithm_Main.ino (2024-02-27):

/*
See https://github.com/Brady-Beecham/Capstone-Team-PowerHouse for more information
*/

#include "ChargeControllerAlgorithm_Main.h"

#define CURRENT_SENSOR_PIN A0
#define MPPC_VOUT_PIN A1
#define PWM_CONTROL_PIN 
#define MINIMUM_INCREMENT  0x02 //TODO: Find a good increment amount
#define MINIMUM_DECREMENT  2 * MINIMUM_INCREMENT

static bool SolarPanelIsGeneratingPower(void);
static void UpdateChargingDutyCycle(void);
static void DisableBatteryCharging(void);
static void PutMCUIntoLowPowerMode(void);
static void DelayBeforeRestartingAlgorithm(void);

static void StoreCurrentAmpsOut(void);
static void IncrementDutyCycle(void);
static void DoubleDecrementDutyCycle(void);
static void ZeroTheDutyCycle(void);
static bool OutputCurrentHasBeenHarmed(void);

static uint16_t ReadCurrentSensor(void);
static uint16_t ReadSolarVout(void);
static void WritePWM(void);

static uint16_t CurrentAmpsOut;
static uint16_t PWM_DutyCycle;

void setup() 
{

}

void loop() 
{
  if(SolarPanelIsGeneratingPower())
  {
    UpdateChargingDutyCycle();
  }
  else
  {
    DisableBatteryCharging();
    PutMCUIntoLowPowerMode();
  }

  DelayBeforeRestartingAlgorithm();
}


void UpdateChargingDutyCycle()
{
  StoreCurrentAmpsOut();

  IncrementDutyCycle();

  if(OutputCurrentHasBeenHarmed())
  {
    DoubleDecrementDutyCycle();
  }
}

bool SolarPanelIsGeneratingPower()
{
  const uint16_t MIN_VOLTAGE_ALLOWED = 0xF0; //TODO: Find an accurate minimum voltage

  return (MIN_VOLTAGE_ALLOWED <= ReadSolarVout());
}

void DisableBatteryCharging()
{
  ZeroTheDutyCycle();
}

void PutMCUIntoLowPowerMode()
{

}

void DelayBeforeRestartingAlgorithm()
{

}

void StoreCurrentAmpsOut()
{
  CurrentAmpsOut = ReadCurrentSensor();
}

void IncrementDutyCycle()
{
  const uint16_t MAXIMUM_DUTY_CYCLE = 0xFF; //TODO: Verify Maximal Rate

  if(PWM_DutyCycle < MAXIMUM_DUTY_CYCLE)
  {
    PWM_DutyCycle += MINIMUM_INCREMENT;
  }

  WritePWM();
}

void DoubleDecrementDutyCycle()
{
  const uint16_t MINIMUM_DUTY_CYCLE = 0x00; //TODO: Verify minimum

  if(PWM_DutyCycle > MINIMUM_DUTY_CYCLE)
  {
    PWM_DutyCycle -= MINIMUM_DECREMENT;
  }

  WritePWM();
}

void ZeroTheDutyCycle()
{
  PWM_DutyCycle = 0;
  WritePWM();
}

bool OutputCurrentHasBeenHarmed()
{
  const uint16_t ACCEPTABLE_RANGE = 0x01; //TODO: Find an acceptable range

  return ReadCurrentSensor() < (CurrentAmpsOut - ACCEPTABLE_RANGE);
}

uint16_t ReadCurrentSensor()
{
  return analogRead(CURRENT_SENSOR_PIN);
}

uint16_t ReadSolarVout()
{
  return analogRead(MPPC_VOUT_PIN);
}

void WritePWM()
{

}

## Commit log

2024-02-20 Initial Charge Controller Main Loop Commit
    Added .h and .ino (to be .c) files and placed some skeleton code inside.
2024-04-09 Added Minimal Charge Controller Experimentation
2024-04-10 Added requirements of deliverable to charge controller section to be completed at a later time
2024-04-10 Charge Controller Continued analysis with C28
2024-04-11 Added Charge Controller Main PCB Problems analysis
2024-04-12 Updates to loop, ground based sensor, power controller sections
2024-04-12 Updates to charge controller section
2024-04-12 Updated Charge Controller Experimentation
2024-04-15 Charge Controller Battery Charging PCB Problems
2024-04-15 Charge Controller Removal of Proposed Changes Section
2024-04-16 Update Power Controller
2024-04-16 Update power Controller results
2024-04-17 Update Power controller updates
2024-04-17 Update Power Controller graphs update
2024-04-17 Update Power Controller graph update
2024-04-17 Update power controller final update
2024-04-17 Added ESP32 testing to Loop Controller section
2024-04-17 Wall Power Clean Up
2024-04-17 Fixed Typos in Wall Power
2024-04-17 Power Controller Clean Up
2024-04-17 Made freq vs time graphs for ESP32 testing smaller
2024-04-28 Added ESP32 image to README.md
2024-04-29 Charge Controller Main PCB
    [ChargeController_Main-B_Cu.gbr, ChargeController_Main-B_Mask.gbr, ChargeController_Main-B_Paste.gbr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]
2024-04-29 Battery Charging PCB Upload
    [LT4020_12_BatCharger-B_Cu.gbr, LT4020_12_BatCharger-B_Mask.gbr, LT4020_12_BatCharger-B_Paste.gbr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]
2024-04-29 Removed brackets around title of README.md
